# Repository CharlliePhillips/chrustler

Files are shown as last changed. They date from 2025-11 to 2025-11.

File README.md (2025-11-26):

# The Chrustler
  Chrustler is a combination of the words 'chord' (what the instrument plays) 'Rust' (the language the software is written in) and 'sampler' (the family of instruments it belongs to). This instrument takes in samples recorded using the device or loaded from a USB drive and detects their frequency. Then the user can play that sample as chords in one of the western music scales. The device runs Raspbian Linux and the Rust program in this repo is started automatically by placing the [autostart folder](https://github.com/CharlliePhillips/chrustler/tree/main/autostart) in `~/.config`. This is my final project for CS3651 (Prototyping Intelligent Devices) at Georgia Tech.  [A video demonstration is available on Youtube.](https://youtu.be/KlqjkN_t0CQ)

## Hardware
  1. Brains: Raspbery Pi Zero 2 W  
    - Runs the software itself.
  2. I2S audio card: IQuadIO Codec Zero  
    - Used for internal mic and speaker, AUX in and out headers.  
    - Also has a 5 band EQ used for the high and low pass filters.
  3. Display: SSD1309 I2C (128x64 2.5in OLED)  
    - Displays current playback information.
  4. Time of Flight sensor: ST Micro VL53L1X  
    - Has 2 regions of interest where the right side controls the level of the high frequencies (low pass filter), and the left side controls the level of the low frequencies (high pass filter)
  5. MCP23017 GPIO extender  
    - Provides additional GPIO for keypad input.
  5. PD Trigger Board  
    - Takes USB-C PD and turns it into 5V to power everything.
  6. USB-C “flush” mount extension  
    - This is intended for installation in a car to add a USB-C port, but provides a way to panel mount the power input (and USB-C is better than micro-B on the pi).
  7. 2x 3.5mm TRS female jacks  
    - Connected to the AUX in and out headers on the Codec Zero for external audio IO.
  8. Micro USB OTG cable  
    - Used to expose a full size USB port for portable loading and storing of sample files.
  9. 1W 8ohm 3.6cm speaker  
    - Connected to the Codec Zero as the internal speaker.
  10. Proto-board  
    - Used for a 5V and ground buses as well as I2C data and clock buses.
  11. Custom PCB for 4x4 Cherry-style mechanical key switches  
    - Designed in KiCAD and manufactured at the GT Hive to hold 16 cherry-style switches and the MCP23017. The KiCAD project and board drawings are in [/keypad_pcb/](https://github.com/CharlliePhillips/chrustler/tree/main/keypad_pcb)  
  12. 16x Otemu Lemon switches  
    - Spare linear Cherry-style switches I had that felt nice for the primary input method.  
  13. 2x Addicore AD267 Rotary Encoders (from class kit)  
    - Included in parts kit for class and used for volume adjustment, IO change, key change, and sample selection.  
  14. 1-2 GPIO duplication module  
    - Gives one set of 40 GPIO pins to connect to the Codec Zero, and another for the other GPIO devices, I2C, and power.  
  15. 8x m2.5 screws & heat set inserts
  16. 12x m3 screws & heat set inserts
  17. 3D printed Chassis  
    - Housing with standoffs to add heat-set inserts, and mount everything nicely. Designed in OpenSCAD.
  18. 3D printed faceplate with acrylic window  
    - Covers the main chassis and has inset text to identify IO ports, Encoder functions, and internal microphone location. Designed in OpenSCAD.  
    - The file for the chassis and faceplate is at [scad/chrustler chassis.scad](https://github.com/CharlliePhillips/chrustler/tree/main/scad/crustler%20chassis.scad).  
  19. 2x 3D printed standoffs  
    - used to support the Codec Zero on top of the Pi accounting for the height added by the GPIO duplicator. Designed in OpenSCAD, file is at [scad/soundcard standoff.scad](https://github.com/CharlliePhillips/chrustler/tree/main/scad/soundcard%20standoff.scad)  
  20. 16x 3D printed keycaps  
    - Custom 3D printed keycaps with the appropriate legends built from the [keycap playground OpenSCAD repo](https://github.com/riskable/keycap_playground).  
    - My modified version of the keycap plaground file is at [/scad/keycap_playground/keycap_playground.scad](https://github.com/CharlliePhillips/chrustler/tree/main/scad/keycap_playground/keycap_playground.scad). This was used to make a base stl file, and then imported to [/scad/legend_caps.scad](https://github.com/CharlliePhillips/chrustler/tree/main/scad/legend_caps.scad) to add the legends.
  21. 2x encoder caps  
    - Spares I had from an SP404-OG after replacing them on that device.

## Libraries
  I wanted to write the software in Rust from the start and it provides a nice way to handle interrupts/multithreading, errors, and has pretty good library support on Raspberry Pi devices. I used Rust's standard library, and a couple of other common ones such as `serde` for storing the time of flight sensor's calibration data. The notable libraries used in the program are:
  1. [pitch-detection](https://docs.rs/pitch-detection/latest/pitch_detection/)  
    - Provides a function for detecting the audio frequency on an array of individual sample points from an audio file.
  1. [awedio](https://docs.rs/awedio/latest/awedio/index.html)  
    - This library handles the playback of samples and provides functions to adjust the speed of the sample (very important for pitch correction) as well as a controller to stop/gate the playing samples.  
    - During development I kept running into an integer overflow issue when playing long samples. To fix this I changed a bunch of the related variables from unsigned 32 bit to unsigned 64 bit numbers.  
    - [My fork](https://github.com/CharlliePhillips/awedio64)
  2. [vl53l1x-rs](https://docs.rs/vl53l1x/latest/vl53l1x/)  
    - This library provides functions for the time of flight sensor.  
    - This nor any other 3rd party library I could find supported all five calibration functions, and so I added wrappers to the ST Micro API for them.  
    - Additionally the `usleep()` function in the ST Micro library this crate wraps wasn't compiling on the Pi, so I changed it to `nanosleep()`.  
    - [My fork](https://github.com/CharlliePhillips/vl53l1x-rs)
  3. [rppal](https://docs.rs/rppal/latest/rppal/)  
    - Provides functions to access the GPIO and I2C hardware on the Pi.
  4. [mcp23017](https://docs.rs/mcp23017/latest/mcp23017/)  
    - Provides functions to interface with GPIO on the MCP23017.
  5. [ssd1306](https://docs.rs/ssd1306/latest/ssd1306/)  
    - Provides structures and functions to interface with an SSD1306 display.  
    - The SSD1306 display is identical to the SSD1309 display used for this project (aside from the physical size, and default address), and by changing the I2C address provided during initialization is cross-compatible.
  6. [embedded-graphics](https://docs.rs/embedded-graphics/latest/embedded_graphics/)  
    - Provides structures and functions for creating the text shown on the display.  

  - The libraries' documentation is linked where their git repos can also be found.

  - I also used the [BOSL2](https://github.com/BelfrySCAD/BOSL2) OpenSCAD library for making cubes with rounded corners.

## Learned Skills
  1. Time of Flight Sensor(s)  
    - Before taking on this project I was totally unaware that this type of distance sensor existed. I had originally intended to use an ultrasonic sensor, or a more traditional IR sensor.  
    - I picked the model of ToF sensor I did because of it's existing Rust library support, and the user programmable Regions of interest. Those regions of interest will still pick up on objects outside the region of interest if they cover enough of the sensor's field of view but work reasonably well with two hands at different distances.  
    - It is pretty easy to interface with the sensor over I2C but they do not come calibrated from the factory and must go through a 3-step calibration process in order to get accurate readings that properly distinguish between the regions of interest.  
      1. SPAD - This is calibrated at the factory but without a cover glass that I used on my prototype. It selects the best of the sub-sensors on the device to use.  
      2. Offset - The device being soldered down and added cover class can introduce an offset in distance readings, this measures and corrects for that.  
      3. Cross-talk - The cover glass can cause some of the light emitted to bounce back into the sensor prematurely. This step compensates for that.  
  2. Heat set inserts (talk about borked one)  
    - I was familiar with this process before but had never done it myself. Getting the holes for the inserts correct took some trial and error, and when it came to insert some for testing I found that making a hole bigger with a soldering iron while the insert is half-inserted is a quick way to get plastic stuck in the insert and make it unusable.
  3. Multi-color 3D printing  
    - I had only done single-colored prints before and OpenSCAD has support for color, but it will not export those colors with STL files. In order to add color I created a small indent in the parts that the Bambu slicer would not recognize as a seperate layer, and then used the color painting/fill tool with edge detection to color the text.  
    - I also found that printing the "base" color before the text caused it to come out messy and distorted. When the text is printed before the rest of each layer though, it comes out crisp and very nice looking.  
    - Example of printing the base color before the text:  
    Example photo  
    - Printing the parts face down (with the text on the bottom layers) also gives the final product a clean, textured finish. See the photos at the end for the final product.
  4. Iterating on CAD designs  
    - The core part of the chassis has a lot of pretty precise measurements to hold everything in place. Instead of re-printing the entire base (10+ hours) each time I had to make an adjustment, I printed skeletons and small sections of the part to make sure everything fit.  
    - Using pins printed where the screws would go later helped hold things in place when test fitting the hardware.  
    - This was also useful for getting the sizing of the keycaps correct given that I'm using a non-standard plate.  
    - The following photos go left to right, top to bottom for first iterations to most recent:  
      - Main Chassis Skeleton:  
      4 iterations of a skeleton for the main chassis
      
      - IO Panel:  
      2 iterations of the rear IO panel with 2xTRS jacks and one USB-C jack  

      - USB panel and restraint:  
      3 iterations of the USB panel and internal restraint posts  

      - Keycaps:  
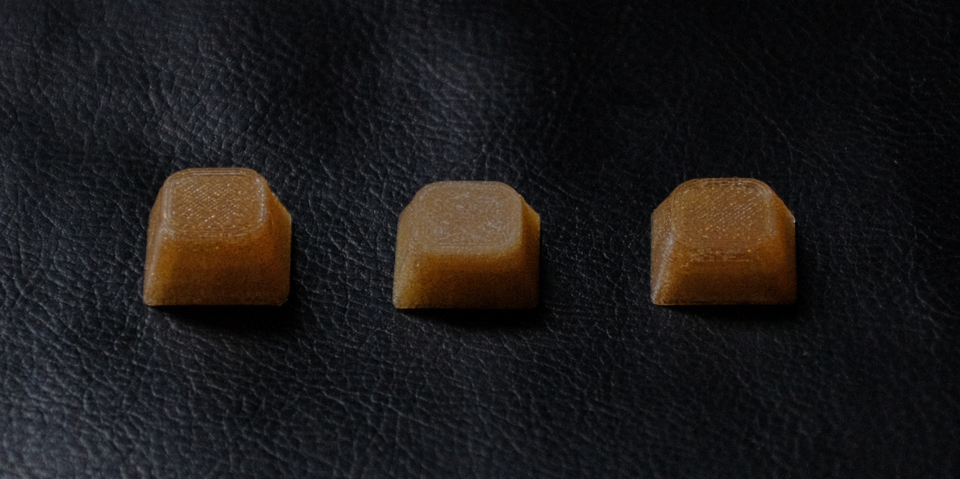
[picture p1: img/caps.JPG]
3 test keycaps of slightly different vertical sizes
        

  5. Linux audio  
    - I've used Linux for quite some time to do multimedia work (always requires some fidling), but I haven't had to get in the weeds quite like this before.  
    - The volume, filter and adjustments along with the IO toggle both use `amixer` commands issued by the Rust program to change the relevant settings. This was easy to test using the `alsamixer` TUI and then translate into commands using the indices given by `amixer -c -1 controls`.  
    - I used `arecord` commands issued by the Rust program to do the audio recording as the simplest Rust interfaces for this were overcomplicated for my use case. When testing recording and playback in the final program I ran into a weird issue with lots of noise in the recordings from the program that didn't exist using the commands by themselves. After some troubleshooting I discovered that the audio device was opened in 32 bit PCM mode by the `awedio` library but I was recording in 16 bit mode as that is the actual format used by the library. Switching the recordings to 32 bit mode fixed this issue.
  6. PCB Fabrication  
    - To have a "macro" pad with Cherry-style switches that fit in the small size I wanted for the enclosure I had to design my own.  
    - Picking up KiCAD to recreate the simple circuit from the membrane pad given in our class kits was fairly easy, and a lot of resources exist online from the custom keyboards community to quickly get a model running. There was also a fellow student familiar with the process who was able to give me some design tips to make sure that my first run of the board would work, and be my last.  
    - The Hive makerspace at school had excellent documentation on using their PCB fabrication equipment (LPKF ProtoMat S103, and ProtoLaser U4). From there it was fairly easy to get everything going, and once finished then I was able to solder the switches and MCP23017 using my own equipment.  
    - The underside of the keypad PCB (the top side is just plain copper):  
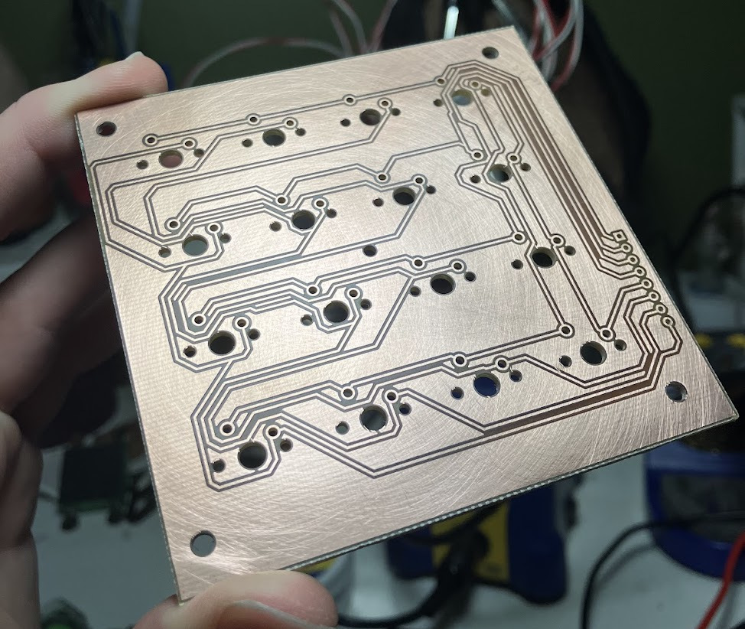
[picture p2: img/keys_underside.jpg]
Copper PCB
    

  7. Acrylic Crazing and I2C Speed/Capacitance Relationship  
    - These two weren't part of skill demos for the class but my instructor Scott taught me about these when I was curious about some of these finer details.  
    - Securing acrylic with the right adhesive is important, as many adhesives will cause stress on top of that introduced by laser cutting. This additional stress can cause micro-cracks called "crazing" and is caused by adhesives with solvents like alcohol. To demo this he sprayed some dry erase fluid on an some laser cut acrylic scrap, and cracks started to form in less than a minute.  
    - I had some extra JB weld and thought that might work well so I used it on another piece of acrylic scrap and attached it to the first chassis skeleton (but it broke during stress testing):  
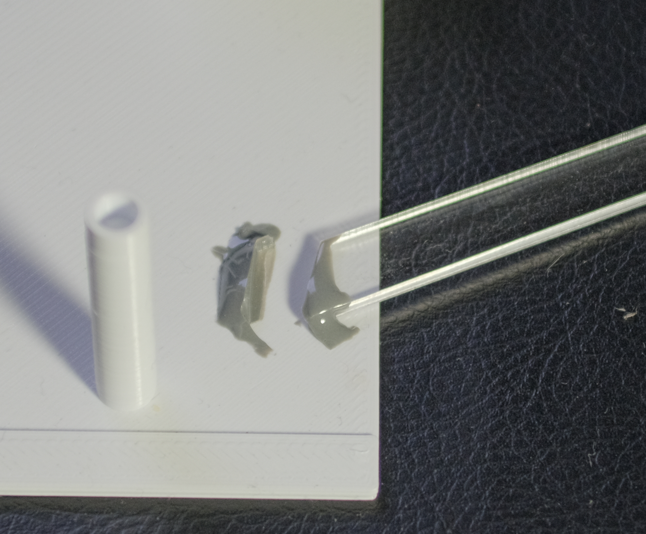
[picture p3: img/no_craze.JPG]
Close up of acrylic and PLA with JB weld globs
      
    - I was worried about cramming too much near the I2C bus circuitry and causing interference. I2C operates at a constant clock but the data experiences some curve in the rise time of the signals. Scott explained how this curve is dictated by the capacitance of the wires which ensured me that I didn't have to be too careful about where to place these signal wires inside of the enclosure.  

## Iteration Process
### Initial Testing
  1. Proof of Concept Program.  
    - My first work on this project was a simple program that recorded a sample, then corrected the pitch it and played back as a C-Major triad.  
    - Once I had acquired some of the hardware for the prototype I added the time of flight sensor readings to adjust a filter on this chord as it looped indefinitely.  
    - [Repo for this test](https://github.com/CharlliePhillips/crustler_poc)
  2. GPIO Test Program   
    - I also created a separate test program to hook up the remainder of the input hardware to to figure out a good setup for reading everything but the TOF sensor.  
    - [Repo for this test](https://github.com/CharlliePhillips/chrustler_btn_test)
  3. Testing Breadboard  
    - For these test programs and much of the development of the main program I had all of the hardware connected to a breadboard. This made it easy to disconnect things to take measurements for the chassis while still working on the main program, and experiment minimizing the wires needed to connect everything.  
    - Having everything on the breadboard made it easy to hook up parts to the chassis skeleton(s):
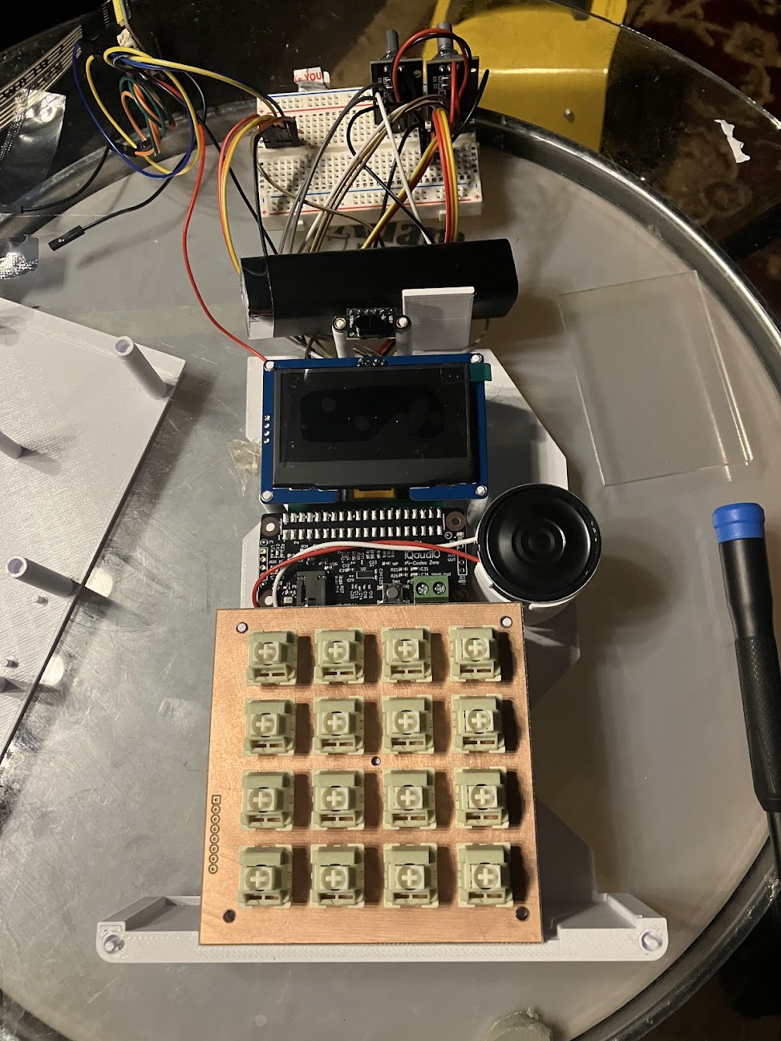
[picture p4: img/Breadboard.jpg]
breadboarded electroncs with some placed on 3D printed skeleton
      

### Ideas That Didn't Work Out
  1. Battery Power  
    - I had initially planned to add battery power to the device for portability. As I worked on the physical design and test fit the rest of the hardware I realized that there would not be a whole lot of room for the battery, and given the time constraint on the project decided that it could do without and USB-C PD would suffice.  
  2. Filter frequency sweeping  
    - I originally wanted to have the TOF sensor control both the frequency and intensity of the filters with a multi-zone sensor where the frequency would be set by the zone(s) and intensity controlled by the distance, but with poor documentation and 3rd party library support this was out of reach.  
    - When moving to a ROI sensor instead of multi-region one I had instead wanted a fixed intensity where the distance controlled the frequency, but I then found that the audio card I had decided on has a built in 5 band EQ, but it is not parametric.  
    - I finally landed on the distance controlling the intensity of the lower two and upper two frequency bands provided by the built in EQ. The intensity of the "inner" band of each side is halved from the intensity set to the highest and lowest end of the EQ, and this works fairly well as a high, low, or band pass filter.

### Hardware That Had To Be Changed
  1. Keypad
    - As alluded to before I originally was using a 4x4 membrane keypad as the primary input for the device. This really sucked,  it was hard to tell when I was pressing the button or not, and it was very small making it a little hard to play multiple chords in succession.
    - This shows how small the original pad was compared to the one I made:  
    final product next to small membrane keypad
    - Creating my own keypad fixed these problems, and also let me change the legends on the keys for a more intuitive arrangement of the inputs.  
  2. SD Card – OTG adapter
    - My original idea for loading external sound files was to use an SD card like on devices like the SP404 MKII and modern (or modernized) MPC devices. This is sort of what the format is intended for, but requires an SPI connection from the limited GPIO I had after adding the sound card.  
    - To simplify things I decided to mount a micro-B OTG adapter inside of the device that connects directly to the Raspberry Pi. This let me focus on getting the file navigation part of my code working correctly and should theoretically not be too difficult if I were to add it in the future.  

### Lessons Learned
  1. Calibrate Your ToF Sensor    
    - Before calibration the ToF sensor readings where all over the place. Adding the Rust calibration functions to the library I used and sitting through the calibration process was something I should have considered from the start and was absolutely worth it.
  2. Consider cable management  
    - Despite not needing to be too worried about I2C interference I should have spent some more time considering where to route all of the wires inside of the device. It is a bit of a rats nest, and with a little more thought, I think I could do much better.  
  3. Test Physical Design With Small Parts   
    - The 3D print iterations shown above were key to getting my physical design just right.  
    - I hadn't taken on a 3D modeling and design project of this scale before, and had never needed to do more than a couple of full prints to get something the way I wanted. I was still pretty uncertain about my measurements at each stage and printing only the parts I was concerned about saved me a lot of time and filament.  
  4. ALSA(mixer) is fun  
    - Using the ALSA programs that come with Raspbian Linux (and most desktop Linux distros) made a lot of things I was uncertain about programming much easier than anticipated.  
    - If I ever do other audio-intense programming projects I will be considering some of these same techniques to make my life easier. I know this is sorta the "Unix Philosophy" but often times built in programs don't come with quite everything I want them to, and this was not the case here.  

  #### Other Potential Improvements
  1. More thorough recording (i.e. adjustable count in, timed recording, input level)  
    - Other sampler instruments offer these sorts of things, and they could be useful here as well.
  2. Simple sample trimming  
    - This would mean you don't have to start playing your recording as soon as or before the recording starts, and would be a very nice qol feature.
  3. Analog Chord Keys  
    - Using optical or hall-effect analog mechanical keyboard switches could be a nice way to keep the same form factor while adding velocity to the input. This would require a more complex PCB though and those switches are much harder to come by.
  4. Stereo sound  
    - All of the sound on this device is mono, and the audio IO is all wired as mono. This was to reduce possibilities while programming and still sounds great (especially for a prototype), but stereo is the standard and would improve the quality of the sound produced.  

## The Final Prototype
A photo taken during assembly:
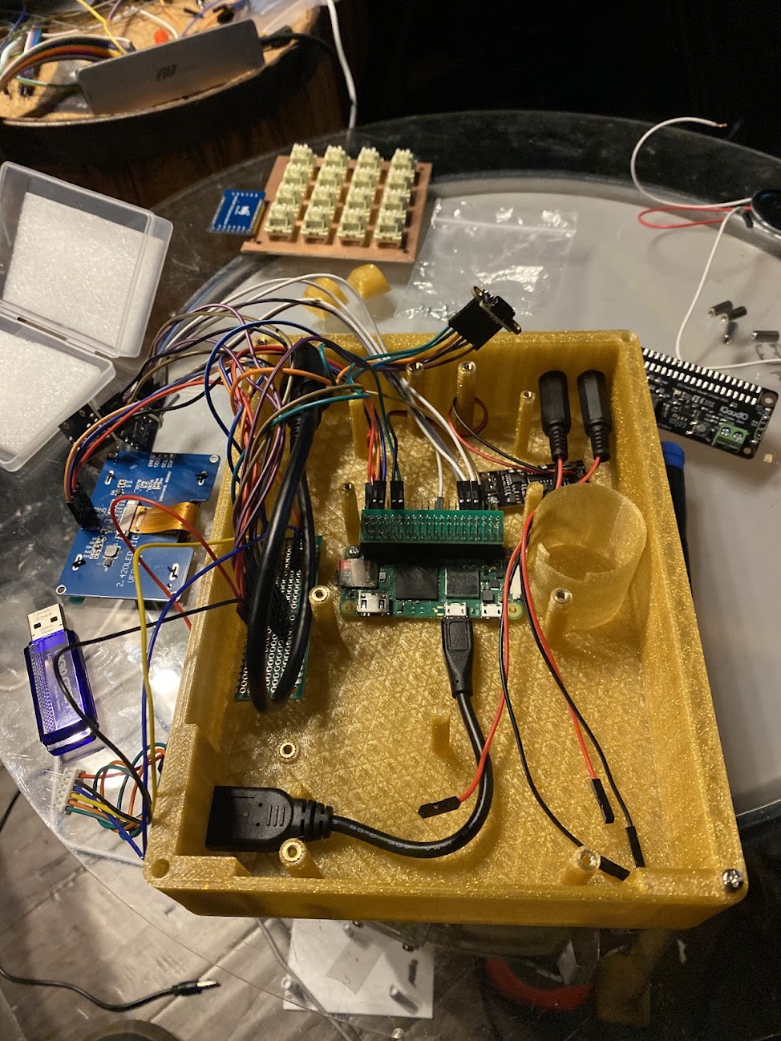
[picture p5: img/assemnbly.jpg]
assembly photo


Overview of the final prototype:
overview photo

Main IO panel on the final prototype:
IO Panel

USB Panel on the prototype:
USB Panel

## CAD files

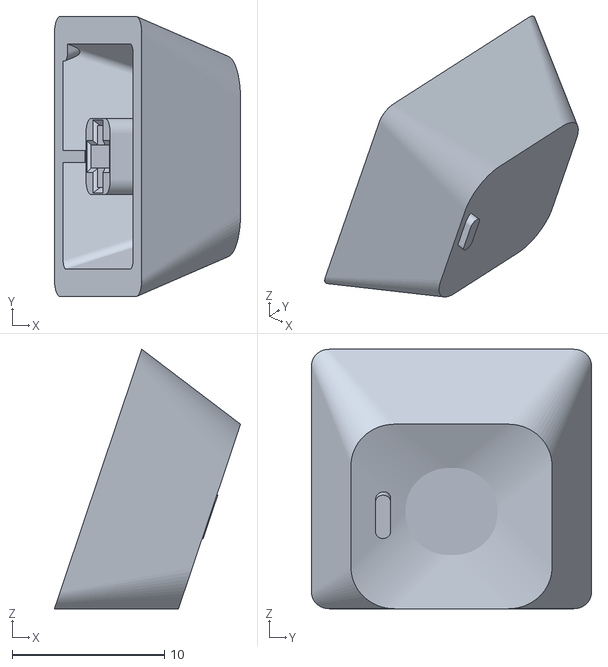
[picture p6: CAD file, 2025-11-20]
scad/keycap_playground/pregenerated/Riskable Profile 4.0 (Homing Dot).stl
12.2 x 18.4 x 17.1

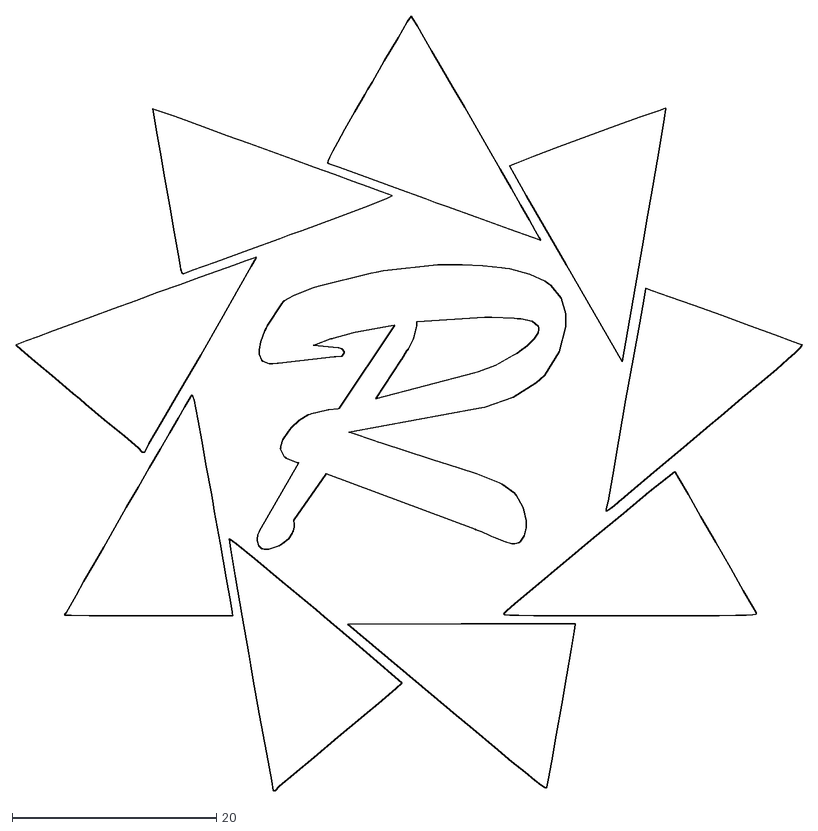
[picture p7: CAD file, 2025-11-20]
scad/keycap_playground/riskable_logo.dxf
76.9 x 75.8

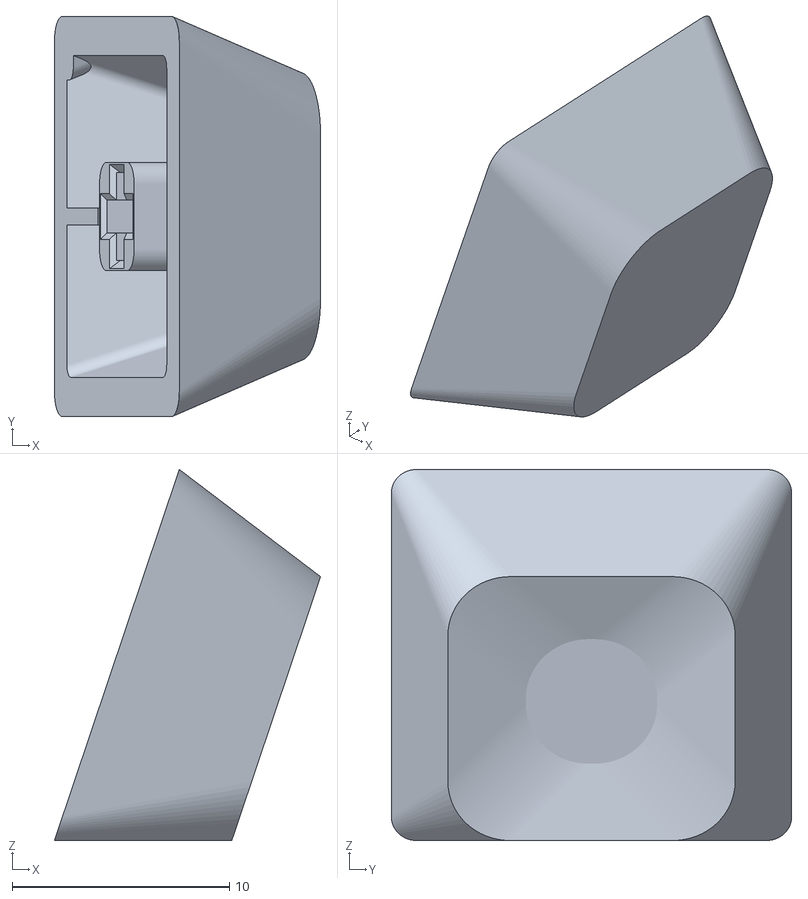
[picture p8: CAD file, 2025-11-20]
scad/keycap_playground/pregenerated/Riskable Profile 4.0.stl
12.2 x 18.4 x 17.1

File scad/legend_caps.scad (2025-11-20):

$fn=32;

difference() {
    import("chrustler_keycap_base.stl");

    translate([0,0,7])
    linear_extrude(.4)
        text("I", size=6, halign = "center", valign = "center");
}

translate([20,0,0])
difference() {
    import("chrustler_keycap_base.stl");

    translate([0,0,7])
    linear_extrude(.4)
        text("II", size=6, halign = "center", valign = "center");
}

translate([40,0,0])
difference() {
    import("chrustler_keycap_base.stl");

    translate([0,0,7])
    linear_extrude(.4)
        text("III", size=6, halign = "center", valign = "center");
}

translate([60,0,0])
difference() {
    import("chrustler_keycap_base.stl");

    translate([0,0,7])
    linear_extrude(.4)
        text("mod", size=5, halign = "center", valign = "center");
}

translate([0,-20,0])
difference() {
    import("chrustler_keycap_base.stl");

    translate([0,0,7])
    linear_extrude(.4)
        text("IV", size=6, halign = "center", valign = "center");
}

translate([20,-20,0])
difference() {
    import("chrustler_keycap_base.stl");

    translate([0,0,7])
    linear_extrude(.4)
        text("V", size=6, halign = "center", valign = "center");
}

translate([40,-20,0])
difference() {
    import("chrustler_keycap_base.stl");

    translate([0,0,7])
    linear_extrude(.4)
        text("VI", size=6, halign = "center", valign = "center");
}

translate([60,-20,0])
difference() {
    import("chrustler_keycap_base.stl");

    translate([0,0,7])
    linear_extrude(.4)
        text("gat", size=6, halign = "center", valign = "center");
}

translate([0,-40,0])
difference() {
    import("chrustler_keycap_base.stl");

    translate([0,0,7])
    linear_extrude(.4)
        text("VII", size=6, halign = "center", valign = "center");
}

translate([20,-40,0])
difference() {
    import("chrustler_keycap_base.stl");

    translate([0,0,7])
    linear_extrude(.4)
        text("<oc", size=5, halign = "center", valign = "center");
}

translate([40,-40,0])
difference() {
    import("chrustler_keycap_base.stl");

    translate([0,0,7])
    linear_extrude(.4)
        text("oc>", size=5, halign = "center", valign = "center");
}

translate([60,-40,0])
difference() {
    import("chrustler_keycap_base.stl");

    translate([0,0,7])
    linear_extrude(.4)
        text("tof", size=6, halign = "center", valign = "center");
}

translate([0,-60,0])
difference() {
    import("chrustler_keycap_base.stl");

    translate([0,0,7.175])
    //linear_extrude(.4)
    //    text("O", size=6, halign = "center", valign = "center");
    cylinder(h=.4,r=3,center=true);
}

translate([20,-60,0])
difference() {
    import("chrustler_keycap_base.stl");

    translate([0,0,7])
    linear_extrude(.4)
        text("f", size=6, halign = "center", valign = "center");
}

translate([40,-60,0])
difference() {
    import("chrustler_keycap_base.stl");

    translate([0,0,7])
    linear_extrude(.4)
        text("hld", size=6, halign = "center", valign = "center");
}

translate([60,-60,0])
difference() {
    import("chrustler_keycap_base.stl");

    translate([0,0,7])
    linear_extrude(.4)
        text("typ", size=6, halign = "center", valign = "center");
}

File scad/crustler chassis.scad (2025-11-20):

$fn = 64;
include<BOSL2/std.scad>

//CHASSIS
union() {
difference() {
    translate([0,0,22.5])
    cuboid([200,150,45], rounding = 5, except = [TOP,BOT] );
    
    translate([0,0,28.5])
        cube([185, 135, 45], center=true);
    
    translate([93.5,-1.5,28.5])
        cube([7, 100, 39], center=true);
    
    translate([18,-69,30])
        cube([80,5,45], center=true);
    
    {//bus support heatset
        translate([-12.5,-48.5,4.5])
        cylinder(h=6, r=2.4,center=true);
        
        translate([52.5,-48.5,4.5])
        cylinder(h=6, r=2.4,center=true);
    }
    
    {//PD support heatset
        translate([-57.25,20,4.5])
        cylinder(h=6.1, r=1.6,center=true);
        
        translate([-42.75,20,4.5])
        cylinder(h=6.1, r=1.6,center=true);
    }
    
    {//PI support heatset
        translate([-21,25.5,4.5])
            cylinder(h=6.1, r=1.6,center=true);
        
        translate([-21,-32.5,4.5])
            cylinder(h=6.1, r=1.6,center=true);
    }
    
    { // heatset lid
        translate([95.5,70.5,42])
            cylinder(h=6.5, r = 2.4, center=true);
        translate([-95.5,70.5,42])
            cylinder(h=6.5, r = 2.4, center=true);
        translate([95.5,-70.5,42])
            cylinder(h=6.5, r = 2.4, center=true);
        translate([-95.5,-70.5,42])
            cylinder(h=6.5, r = 2.4, center=true);
    }
    
    translate([-96.25,-55,25]) { // PWR jack
        difference() {
            rotate([0,90,0])
                cylinder(h=9, r = 8, center=true);
            
            translate([0,8.125,0])
                cube([9,1,5],  center = true);
        }
    }
    
    { //HP jack
        translate([-96.25,60,25])
        rotate([0,90,0])
            cylinder(h=9, r = 4.75, center=true);
        
        //translate([-94.8,55,25])
        translate([-95.05,60,25])
        rotate([0,90,0])
            cylinder(h=7.5, r = 5.875, center=true);
    }
    
        { //in jack
        translate([-96.25,45,25])
        rotate([0,90,0])
            cylinder(h=9, r = 4.75, center=true);
        
        //translate([-94.8,55,25])
        translate([-95.05,45,25])
        rotate([0,90,0])
            cylinder(h=7.5, r = 5.875, center=true);
    }
    
    { // USB jack
        translate([75, -71.25, 11.25])
            cube([14.5, 8, 7.5], center=true);
        
        translate([75, -69, 11.75])
            cube([18.5, 7.5, 11.5], center=true);
    }
}
    
    {//USB restraint
        translate([84,-44,9.5])
            cube([4, 4, 8],center=true);
        
        translate([66,-44,9.5])
            cube([4, 4, 8],center=true);
    }
    
    difference() {
    translate([-10,48,6]) difference() { // speaker support
        cylinder(h=36.7,r=18,center=false);
        
        cylinder(h=37,r=17, center=false);
        translate([0,-18,19])
        cube([12,4,37],center = true);
    }
        translate([48, -1.75, 40])
        cube([94,94,6], center=true);
    }
    translate([51,-1.75,6]) { // keys support
        difference() {
            translate([38,40,0])
            cylinder(h=30, r=3.5,center=false);
            
            translate([38,40,24])
            cylinder(h=6.1, r=2.4,center=false);
        }
        difference() {
            translate([38,-37,0])
            cylinder(h=30, r=3.5,center=false);
            
            translate([38,-37,24])
            cylinder(h=6.1, r=2.4,center=false);
        }
        difference() {
            translate([-39,40,0])
            cylinder(h=30, r=3.5,center=false);
            
            translate([-39,40,24])
            cylinder(h=6.1, r=2.4,center=false);
        }
        difference() {
            translate([-39,-37,0])
            cylinder(h=30, r=3.5,center=false);
            
            translate([-39,-37,24])
            cylinder(h=6.1, r=2.4,center=false);
        }
        difference() {
            translate([-1,2,0])
            cylinder(h=30, r=2.75,center=false);
            
            //translate([-1,2,28])
            //cylinder(h=4.1, r=1.98,center=false);
        }
        translate([-1,2,28])
            cylinder(h=8, r = 0.8, center=true); 
    }
    
    translate([20,-48.5,0]) { // Bus board support
        translate([-32.5,0,6])
        difference() {
                cylinder(h=3, r=3.5,center=true);
                cylinder(h=6, r=2.4,center=true);
        }
        
        translate([32.5,0,6])
        difference() {
            cylinder(h=3, r=3.5,center=true);
            cylinder(h=6, r = 2.4, center=true);
        }
     }
     
        translate([-50,20,0]) { // PD board support
            translate([-7.25,0,6])
            difference() {
                cylinder(h=3, r=2.75,center=true);
                cylinder(h=6.1, r=1.6,center=true);
            }
            translate([7.25,0,6])
            difference() {
                cylinder(h=3, r=2.75,center=true);
                cylinder(h=6.1, r=1.6,center=true);
            }
            translate([0,34,6])
                cube([14,2,3], center=true);

     }
    
    translate([0,3.5,0]){ // pi support
    translate([2,22,6])  {
        cylinder(h=.5, r=2.75,center=true);
            translate([0,0,2])
            cylinder(h=4, r = 0.8, center=true);
    }
    translate([2,-36,6])  {// pi support
        cylinder(h=.5, r=2.75,center=true);
            translate([0,0,2])
            cylinder(h=4, r = 0.8, center=true);
    }
    translate([-21,22,6])  {
        difference() {
            cylinder(h=.5, r=2.75,center=true);
            //translate([0,0,2])
            //cylinder(h=4, r = 1.175, center=true);
            cylinder(h=6.1, r=1.6,center=true);
        }
    }
    translate([-21,-36,6])  {
        difference() {
            cylinder(h=.5, r=2.75,center=true);
            //translate([0,0,2])
            //cylinder(h=4, r = 1.175, center=true
            cylinder(h=6.1, r=1.6,center=true);
        }
    }

    }
    translate([-50, 0,6]) { // display support
        difference() {
            translate([21.5,32.5,0])
            cylinder(h=33, r=2.75,center=false);
            
            //translate([21.5,32.5,29])
            //cylinder(h=4.1, r=1.98,center=false);
        }
        translate([21.5,32.5,30.5])
            cylinder(h=8, r = 1.175, center=true); 
        
        difference() {
            translate([-21.5,32.5,0])
            cylinder(h=33, r=2.75,center=false);
            
            translate([-21.5,32.5,27])
            cylinder(h=6.1, r=1.6,center=false);
        }
        
        difference() {
            translate([21.5,-32.5,0])
            cylinder(h=33, r=2.75,center=false);
            
            translate([21.5,-32.5,27])
            cylinder(h=6.1, r=1.6,center=false);
        }
        
        difference() {
            translate([-21.5,-32.5,0])
            cylinder(h=33, r=2.75,center=false);
            
            //translate([-21.5,-32.5,29])
            //cylinder(h=4.1, r=1.98,center=false);
        }
        translate([-21.5,-32.5,30.5])
            cylinder(h=8, r = 1.175, center=true); 
    }
    
    
        translate([-84, 0,6]) { // tof support
        difference() {
            translate([0,10,0])
            cylinder(h=36, r=3.5,center=false);
            
            translate([0,10,30])
            cylinder(h=6.1, r=2.4,center=false);
        }
        difference() {
            translate([0,-10,0])
            cylinder(h=36, r=3.5,center=false);
            
            translate([0,-10,30])
            cylinder(h=6.1, r=2.4,center=false);
        }
    }
}
// M2.5 holes
// cylinder(h=4, radius = 1.98, center=true);

//M3 holes
// cylinder(h=4, radius = 2.4, center=true);

translate([0,0,146.5]) { // LID 
    //translate([0,0,23.25])
    
difference() {
    translate([0,0,-0.5])
    cuboid([200,150,2], rounding = 5, except = [TOP,BOT] );
    
    translate([2,-26.5,0])
    cylinder(h=4, r=1, center=true);
    
    { // TOF cavity
        translate([-82.5,0,0])
        cuboid([5.75,10.5,4], rounding = 2.875, except = [TOP,BOT]);
    }
    
    { // display cavity
        translate([-50,0,0])
            cube([48,70.2,4], center=true);
        translate([-50.5,-.5,-1.025])
            cube([52,74.2,1], center=true);
    }
    
    translate([0,0,-0.25]) { // pot text inset
        translate([-25,-54,.6])
        rotate([0,0,90])
        linear_extrude(.45,center=true)
        text("VOL/IO", size = 6, halign = "center", valign= "center");
        
        translate([25,-57,.6])
        rotate([0,0,90])
        linear_extrude(.45,center=true)
        text("KEY/SND", size = 6, halign = "center", valign= "center");
        
        translate([2,-16,.6])
        rotate([0,0,90])
        linear_extrude(.45,center=true)
        text("MIC", size = 6, halign = "center", valign= "center");
        
        translate([-92,0,.6])
        rotate([0,0,90])
        linear_extrude(.395,center=true)
        text("TOF", size = 6, halign = "center", valign= "center");
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

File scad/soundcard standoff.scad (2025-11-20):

$fn = 64;
include<BOSL2/std.scad>
translate([0,0,9.9])
difference() {
    cylinder(h=19.8, r = 2.75, center=true);
    
    translate([0,0,6.9])
    cylinder(h=6.1, r = 1.7, center=true);
    
    translate([0,0,-8])
    cylinder(h=4, r = 1.6, center=true);
}
//translate([5,5,4])
//union() {
//    cylinder(h=8, r = 2.75, center=true);
    
//    translate([0,0,6])
//    cylinder(h=4, r = 1.175, center=true);
//}

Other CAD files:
scad/keycap_playground/keycap_playground.scad
scad/keycap_playground/constants.scad
scad/keycap_playground/keycaps.scad
scad/keycap_playground/legends.scad
scad/keycap_playground/profiles.scad
scad/keycap_playground/snap_fit.scad
scad/keycap_playground/stems.scad
scad/keycap_playground/utils.scad

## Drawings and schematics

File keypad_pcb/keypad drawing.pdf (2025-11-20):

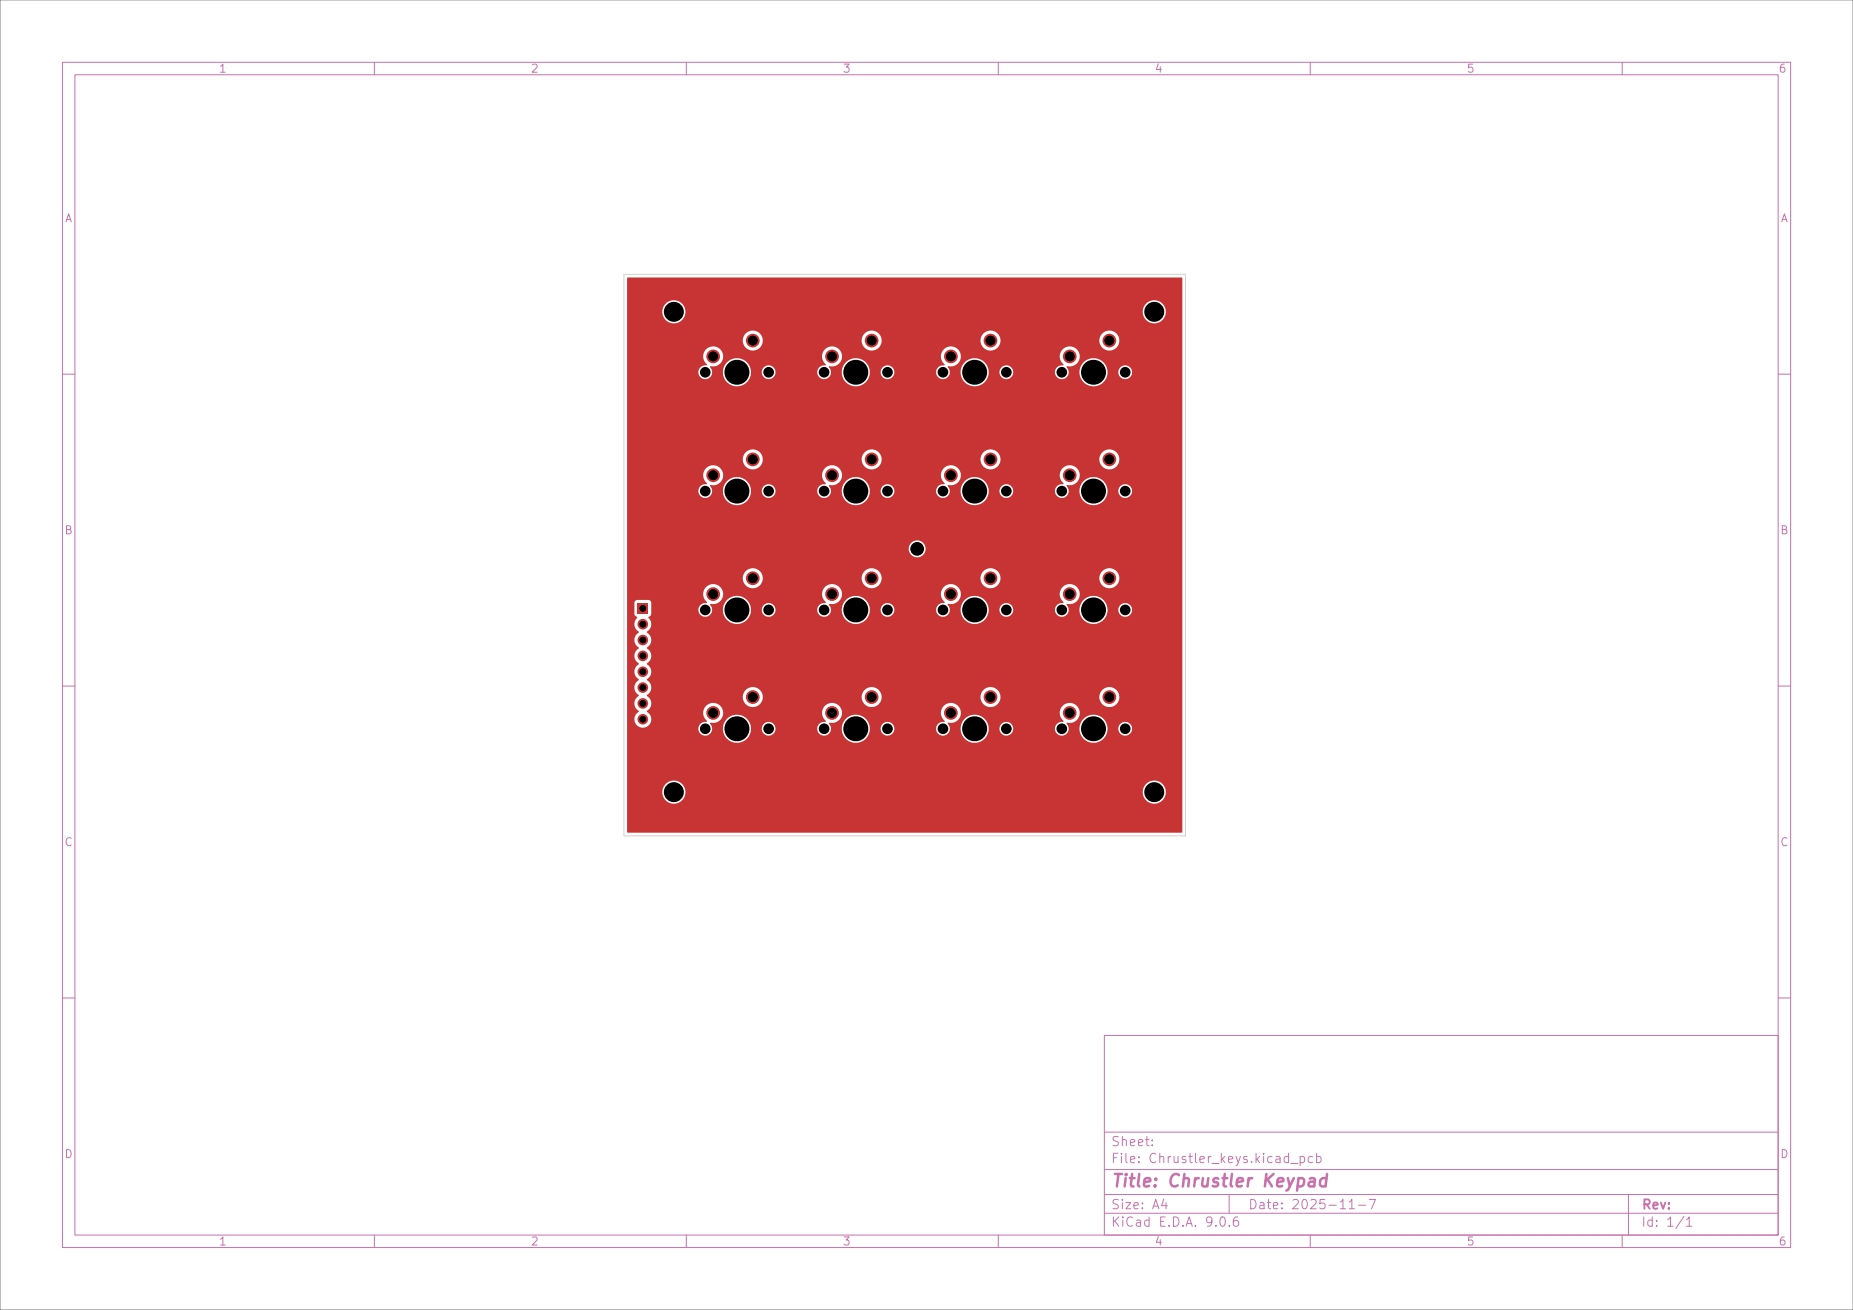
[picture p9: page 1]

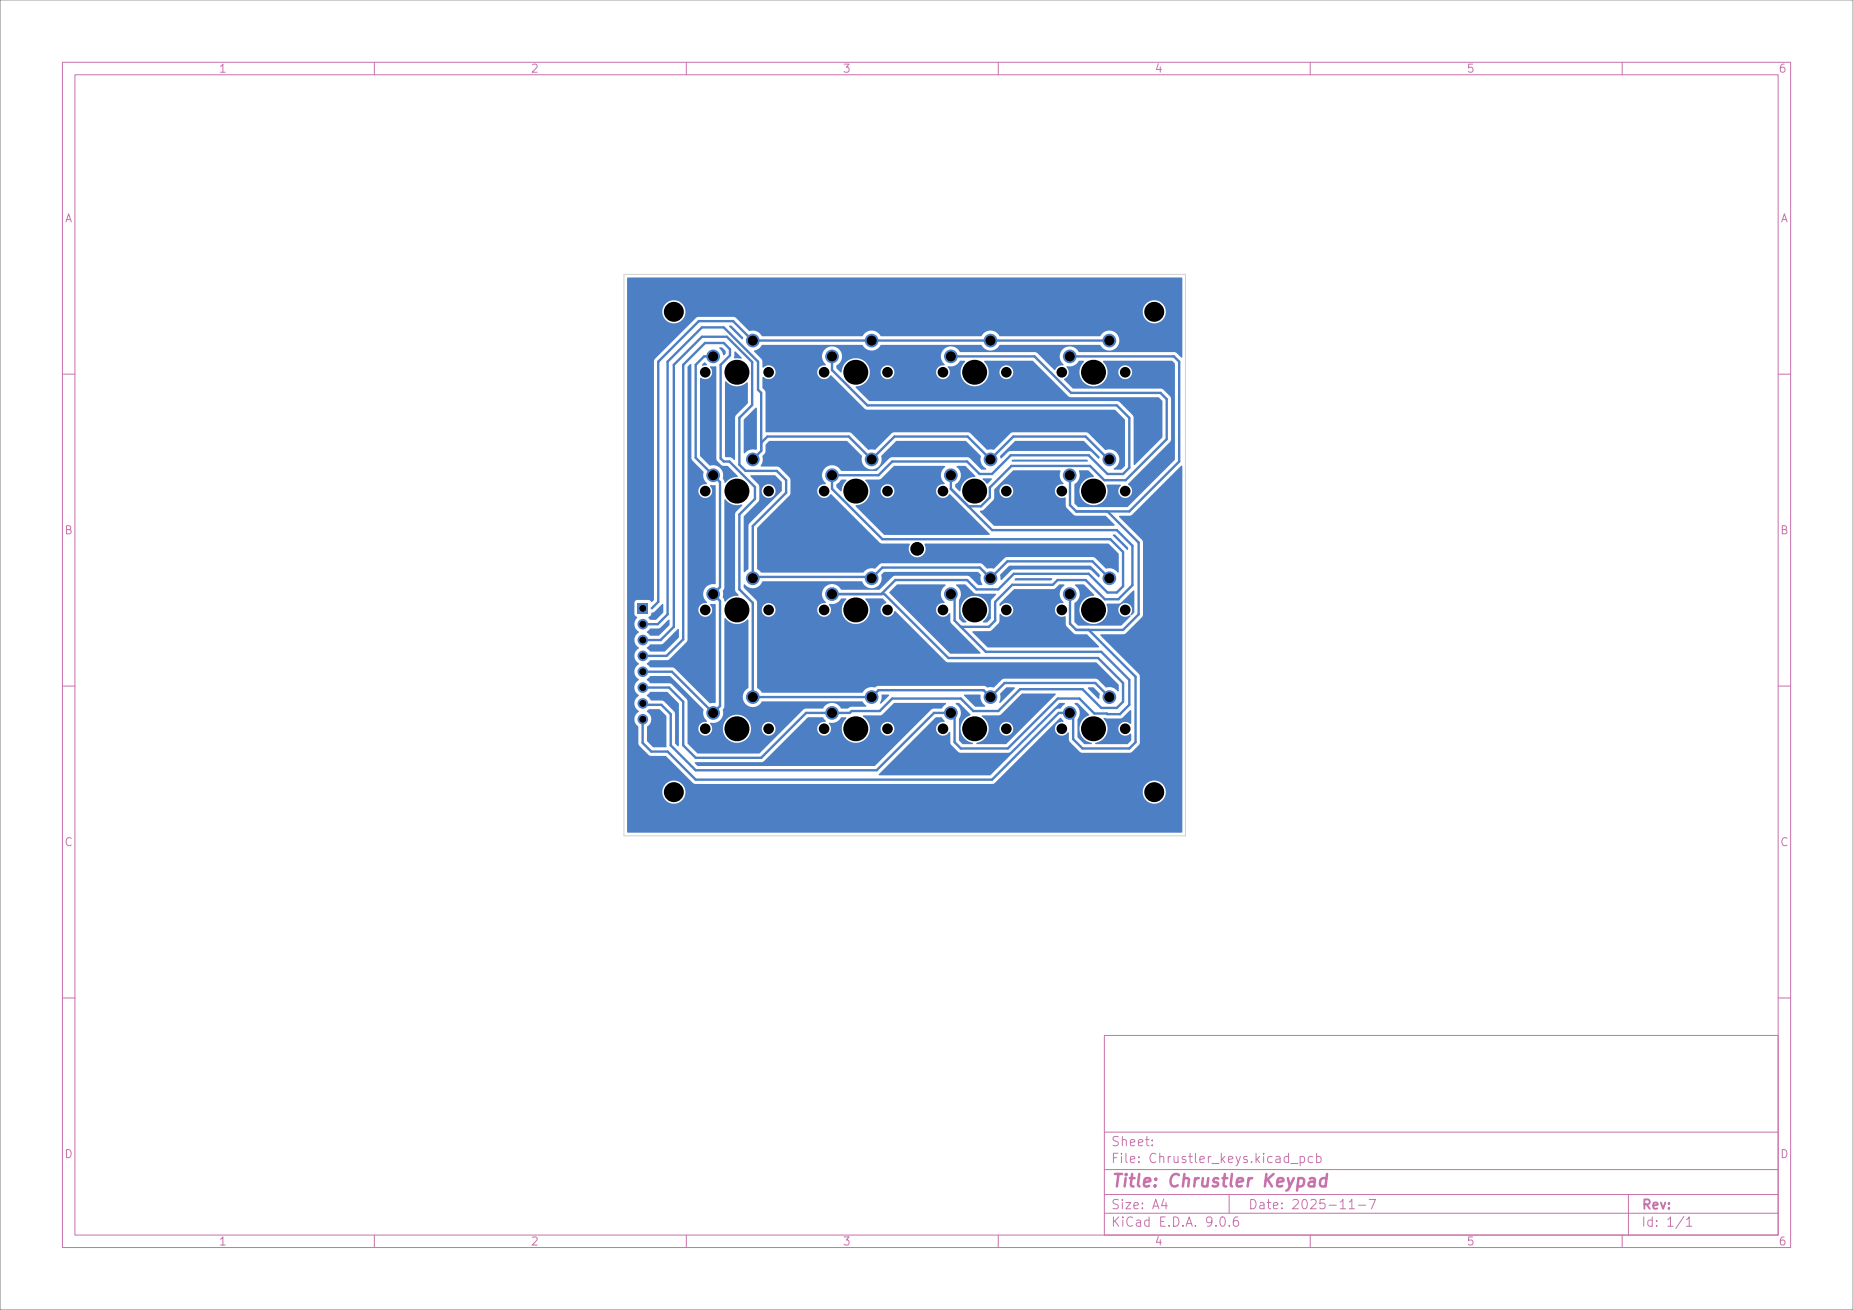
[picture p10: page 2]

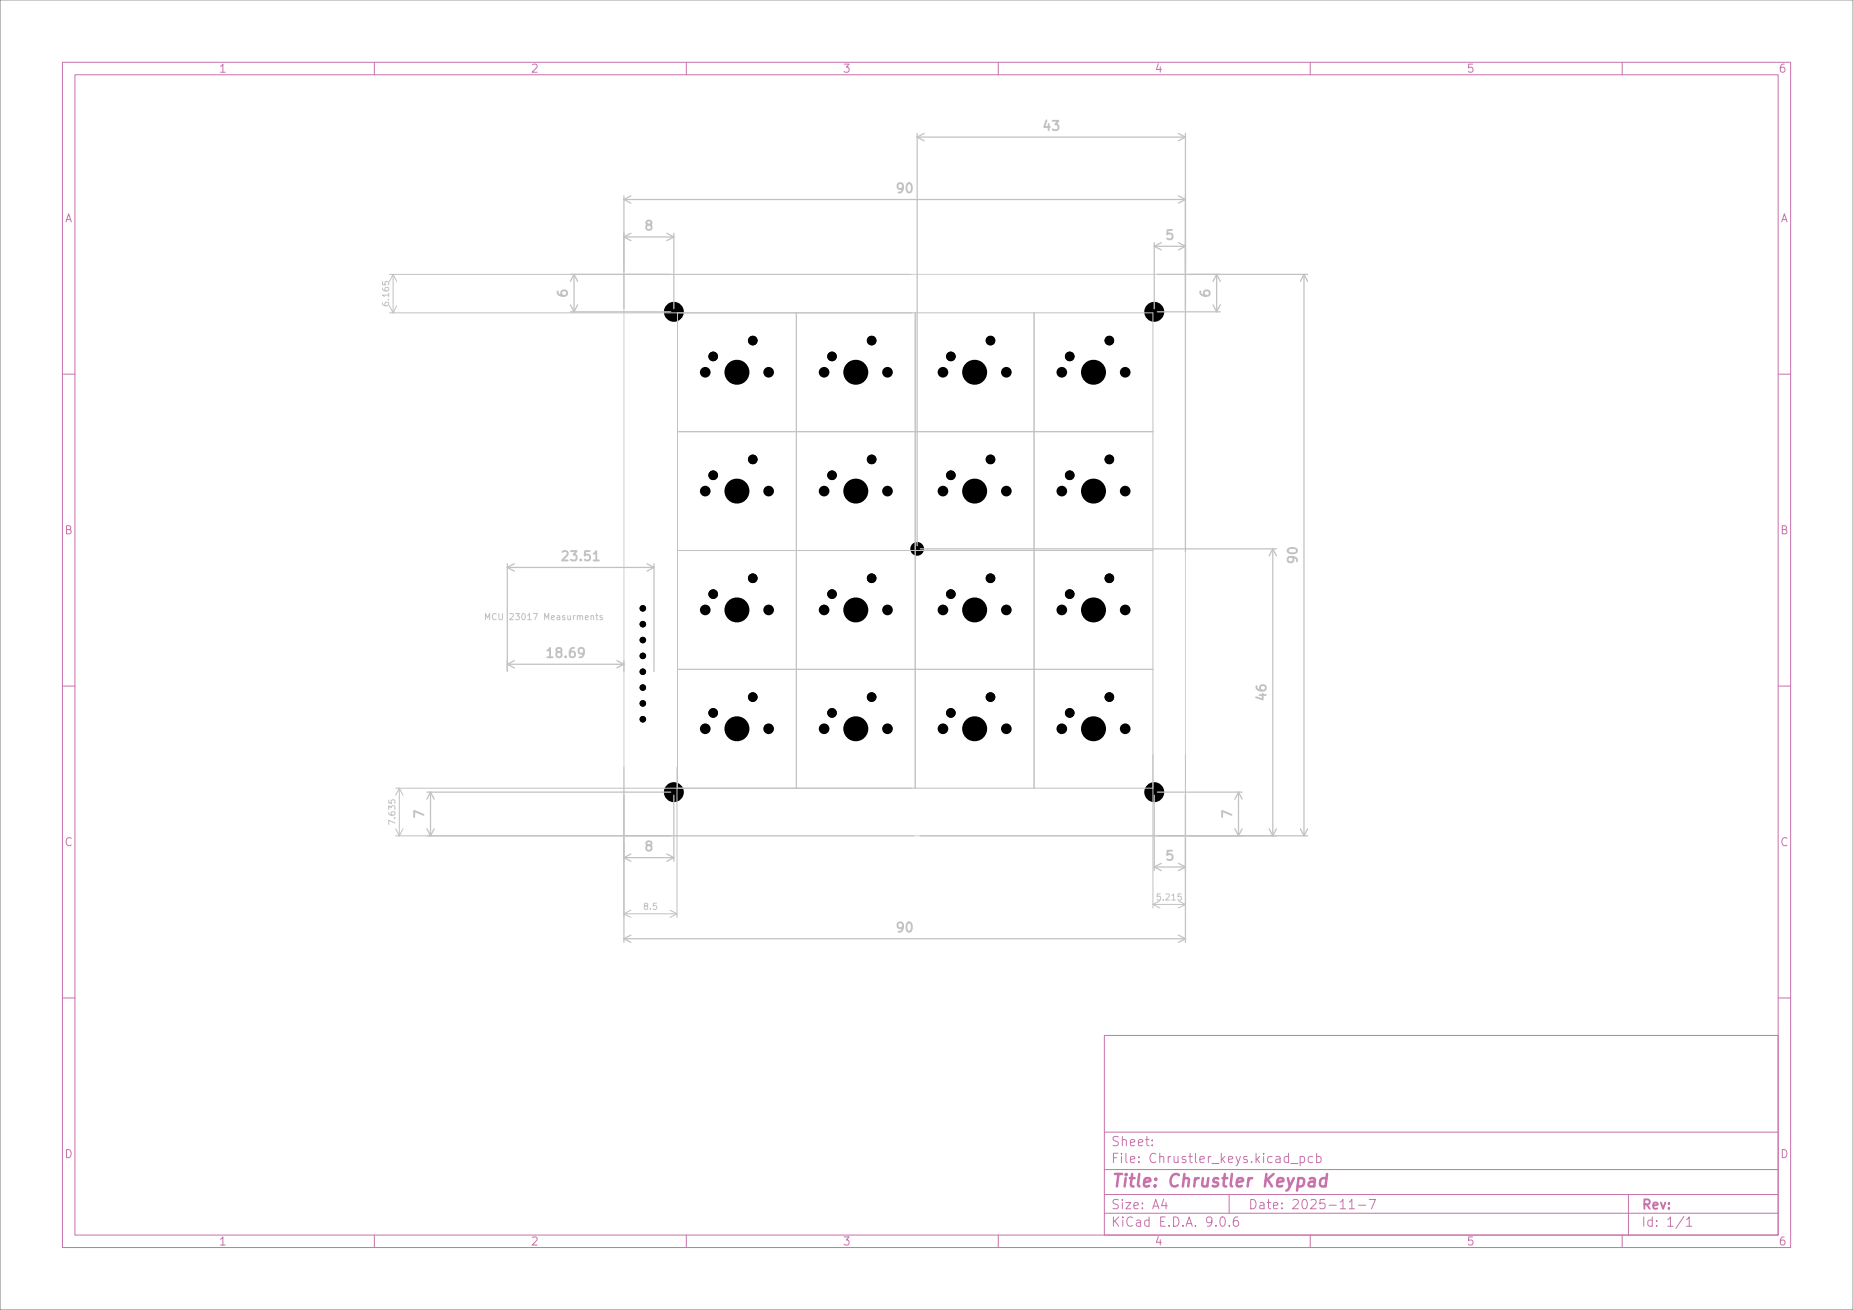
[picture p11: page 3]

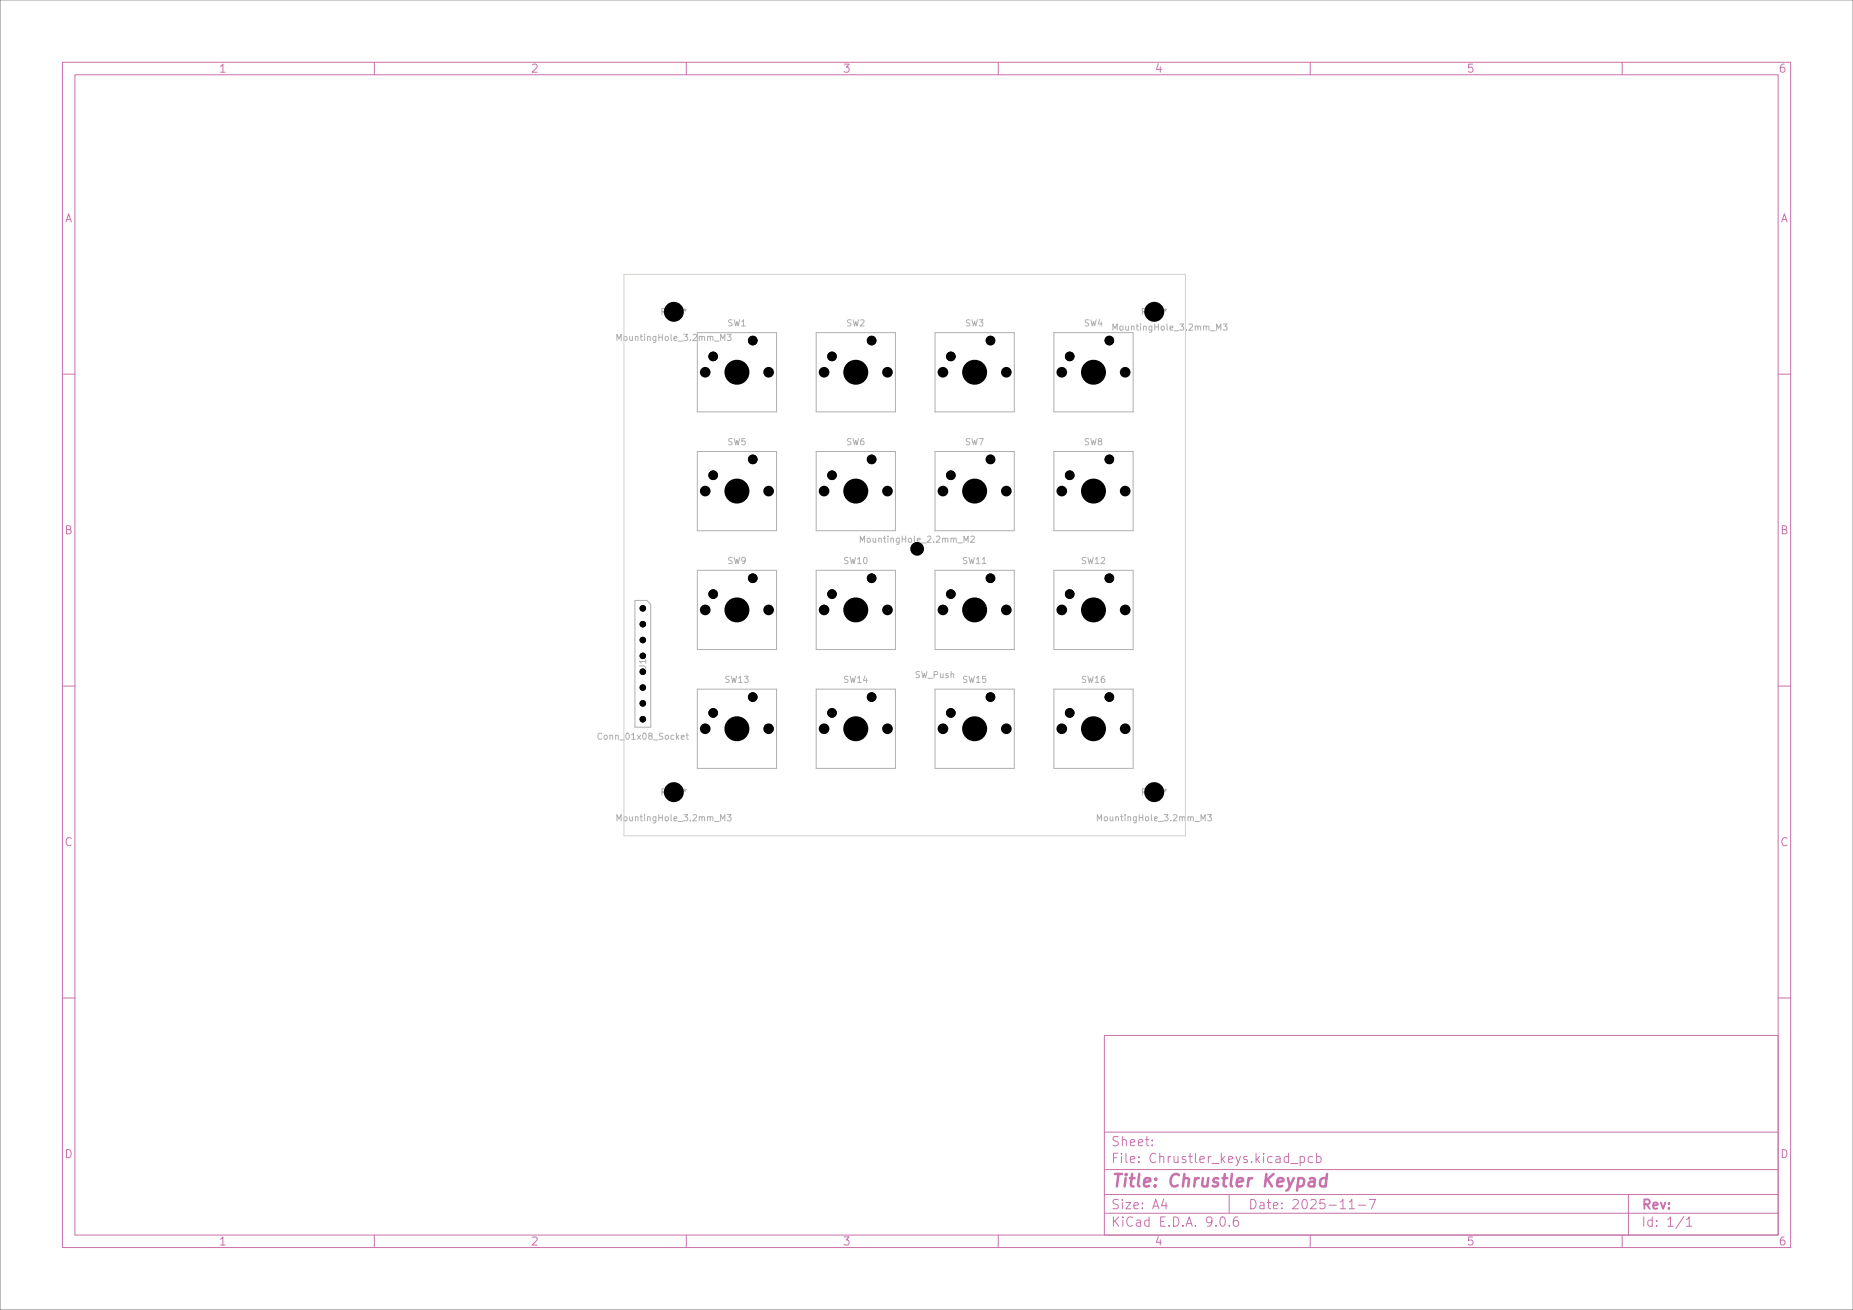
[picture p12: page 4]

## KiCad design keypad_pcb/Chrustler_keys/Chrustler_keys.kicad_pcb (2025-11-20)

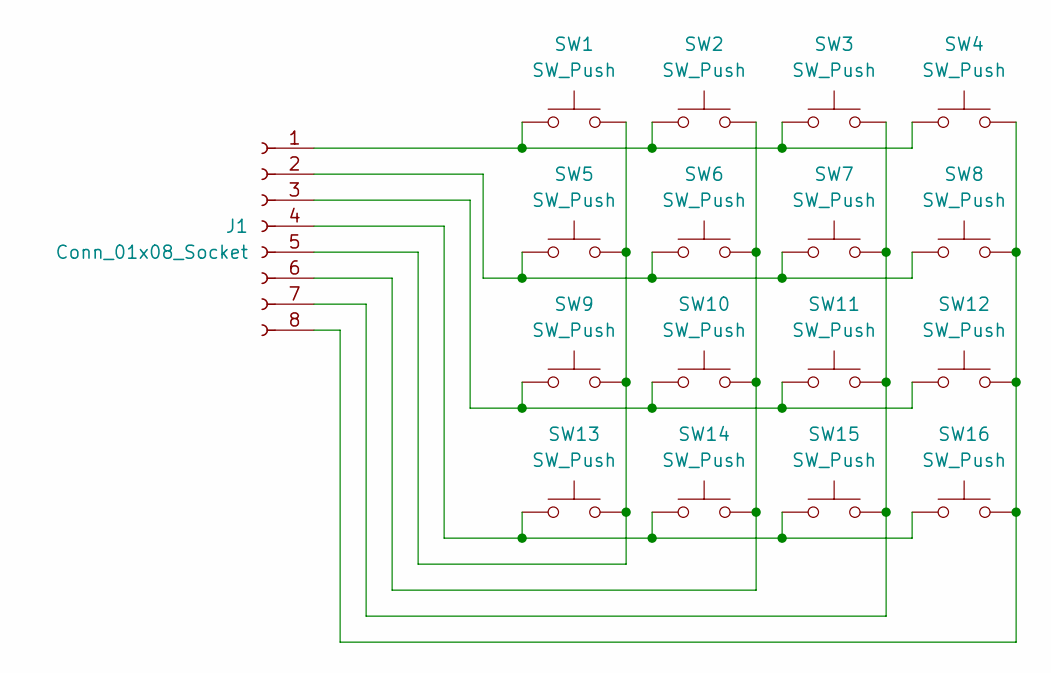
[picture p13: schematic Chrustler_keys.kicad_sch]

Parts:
J1: Conn_01x08_Socket; PinSocket_1x08_P2.54mm_Vertical
SW1, SW2, SW3, SW4, SW5, SW6, SW7, SW8, SW9, SW10, SW11, SW12, SW13, SW14, SW15, SW16: SW_Push; SW_Cherry_MX_1.00u_PCB

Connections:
unnamed: J1.1, SW1.1, SW2.1, SW3.1, SW4.1
unnamed: J1.2, SW5.1, SW6.1, SW7.1, SW8.1
unnamed: J1.3, SW9.1, SW10.1, SW11.1, SW12.1
unnamed: J1.4, SW13.1, SW14.1, SW15.1, SW16.1
unnamed: J1.5, SW1.2, SW5.2, SW9.2, SW13.2
unnamed: J1.6, SW2.2, SW6.2, SW10.2, SW14.2
unnamed: J1.7, SW3.2, SW7.2, SW11.2, SW15.2
unnamed: J1.8, SW4.2, SW8.2, SW12.2, SW16.2

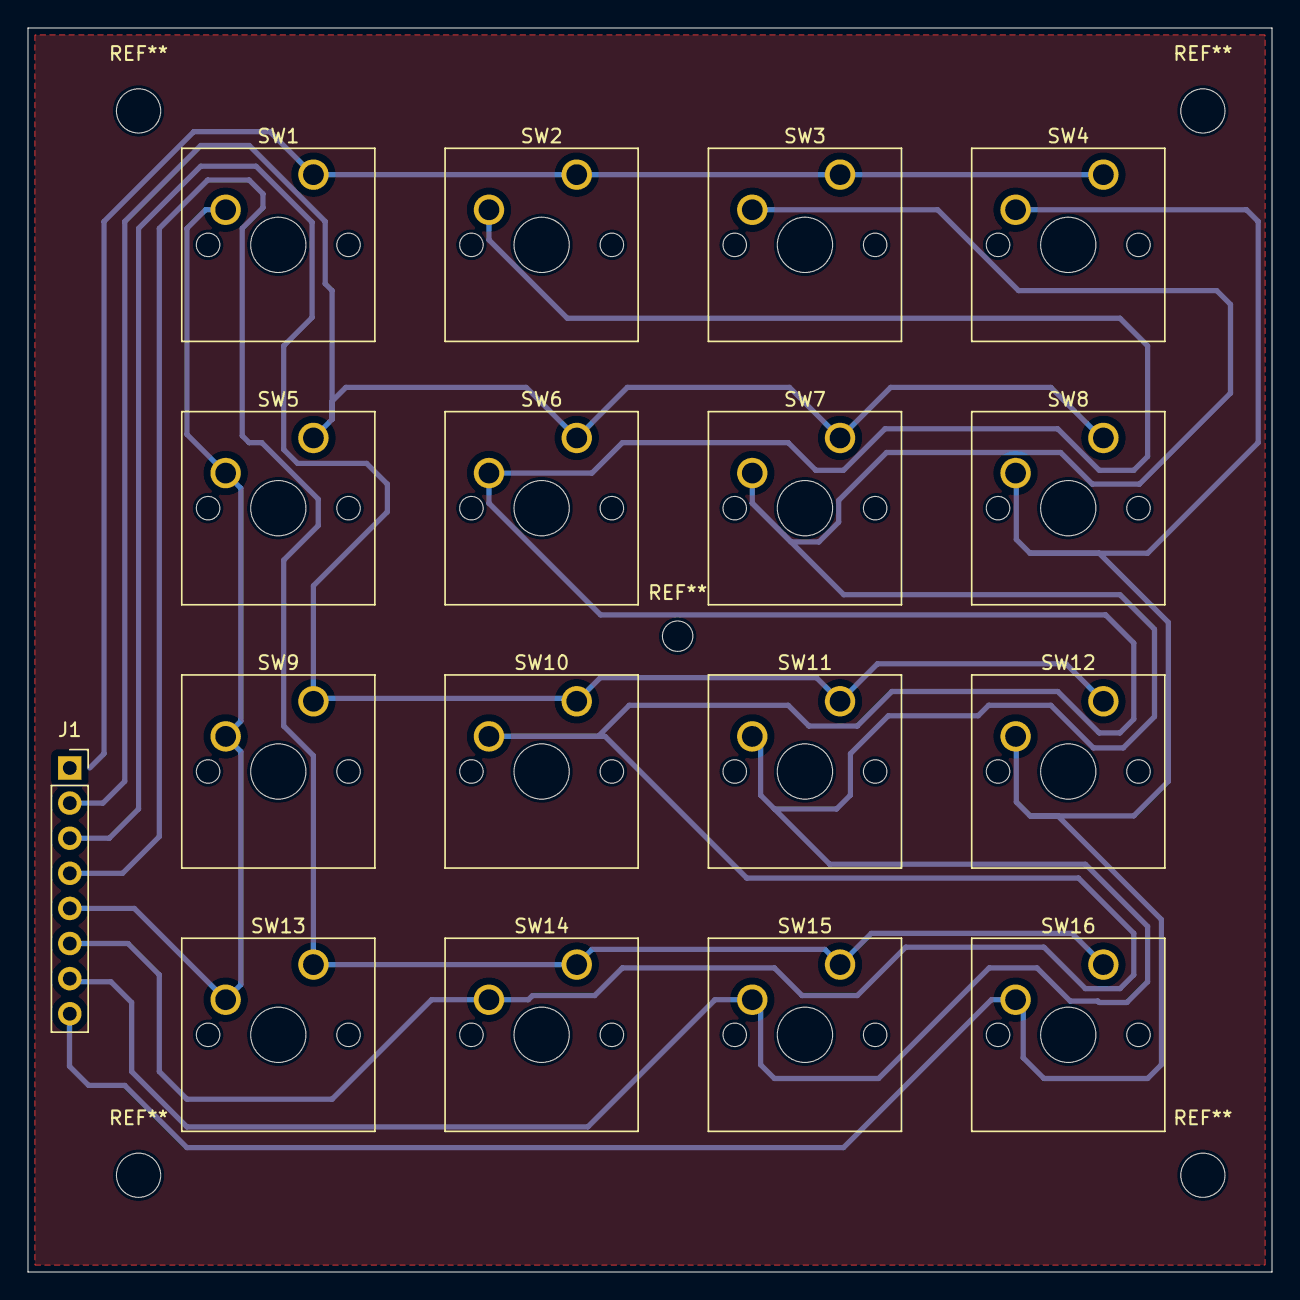
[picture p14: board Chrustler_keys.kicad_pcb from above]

Board: 2 copper layers, 90.0 x 90.0 mm, 17 parts (0 on the bottom side), 8 nets.

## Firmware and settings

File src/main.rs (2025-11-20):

use awedio::{backends::{CpalBackend, CpalBufferSize}, manager::Manager, sounds::{MemorySound, wrappers::{AdjustableSpeed, Controllable, Controller, Pausable, Stoppable}}, *};
use nix::libc::major;
use pitch_detection::{detector::{mcleod::McLeodDetector, PitchDetector}, *};
use rppal::{gpio::{Event, Gpio, InputPin, Trigger}, i2c::I2c};
use core::num;
use std::{env, fmt::format, fs, path, sync::{Arc, Mutex, atomic::{AtomicBool, AtomicI64, AtomicU16}}, thread::{current, sleep}, time::{Duration, Instant}};
use std::fs::File;
use std::io::Read;
use embedded_graphics::{
    mono_font::{MonoTextStyleBuilder, ascii::{FONT_6X10, FONT_8X13}},
    pixelcolor::BinaryColor,
    prelude::*,
    text::{Baseline, Text},
};
use ssd1306::{mode::BufferedGraphicsMode, prelude::*, I2CDisplayInterface, Ssd1306};
use vl53l1x::{Vl53l1x, Vl53l1xRangeStatus, CalibrationData, CustomerNvmManaged, AdditionalOffsetCalData, OpticalCentre, GainCalibrationData, CalPeakRateMap};
use mcp23017::MCP23017;
use num_traits::pow::Pow;

// use crate::keypad::*;
// use crate::encoders::*;
// use crate::tof::*;
mod keypad;
mod encoders;
mod tof;
use tof::CalibrationDataRem;



const SAMPLE_RATE: usize = 48000;
const SIZE: usize = 1024;
const PADDING: usize = SIZE / 2;
const POWER_THRESHOLD: f64 = 0.0001;
const CLARITY_THRESHOLD: f64 = 0.25;

const TEMP_PIN: u8 = 27;
const TOF_INT_PIN: u8 = 17;

const DEFAULT_EQ_LEVEL: u16 = 12;
const VOL_LUT: [u16; 76] = [0,5,9,13,17,20,24,26,29,32,34,37,39,41,43,45,47,48,50,52,53,55,56,58,59,60,61,63,64,65,66,67,68,70,71,72,73,74,75,75,76,77,78,79,80,81,81,82,83,84,85,85,86,87,87,88,89,89,90,91,91,92,93,93,94,94,95,96,96,97,97,98,98,99,99,100];

const TRIADS: u16 = 3;
const SEVENTHS: u16 = 4;
const NINTHS: u16 = 5;

const MAJ_MUL: [f64; 15] = [1.0, 1.1225, 1.2599, 1.3348, 1.4983, 1.6818, 1.887, 2.0, 2.2449, 2.5198, 2.6697, 2.9966, 3.3636, 3.7755, 4.0];
const MIN_MUL: [f64; 15] = [1.0, 1.1225, 1.1892, 1.3348, 1.4983, 1.5874, 1.7818, 2.0, 2.2449, 2.3784, 2.6697, 2.9966, 3.1748, 3.5636, 4.0];

const INPUT_TIMEOUT: u64 = 150;
const FULLSCREEN_TIMEOUT: u64 = 75;

#[derive(Clone, Copy)]
enum Chords {
    I,
    i,
    ii,
    iid,
    III,
    iii,
    IV,
    iv,
    V,
    v,
    vi,
    VI,
    vii,
    VII
}

impl Chords {
    fn note_indices(self) -> Vec<u16> {
        match self {
            Chords::I => vec![1, 3, 5, 7, 9],
            Chords::i => vec![1, 3, 5, 7, 9],
            Chords::ii => vec![2, 4, 6, 8, 10],
            Chords::iid => vec![2, 4, 6, 8, 10],
            Chords::III => vec![3, 5, 7, 9, 11],
            Chords::iii => vec![3, 5, 7, 9, 11],
            Chords::IV => vec![4, 6, 8, 10, 12],
            Chords::iv => vec![4, 6, 8, 10, 12],
            Chords::V => vec![5, 7, 9, 11, 13],
            Chords::v => vec![5, 7, 9, 11, 13],
            Chords::vi => vec![6, 8, 10, 12, 14],
            Chords::VI => vec![6, 8, 10, 12, 14],
            Chords::vii => vec![7, 9, 11, 13, 15],
            Chords::VII => vec![7, 9, 11, 13, 15]
        }
    }
}

#[derive(Clone, Copy, Debug)]
enum Key {
    C,
    Cs,
    D,
    Ds,
    E,
    F,
    Fs,
    G,
    Gs,
    A,
    As,
    B
}

const KEYS: [Key; 12] = [Key::C, Key::Cs, Key::D, Key::Ds, Key::E, Key::F, Key::Fs, Key::G, Key::Gs, Key::A, Key::As, Key::B];

impl Key {
    fn frequency(self) -> f64 {
        match self {
            Key::C => {
                261.63
            }
            Key::Cs => {
                277.2
            }
            Key::D => {
                283.66
            }
            Key::Ds => {
                311.1
            }
            Key::E => {
                329.63
            }
            Key::F => {
                349.23
            }
            Key::Fs => {
                370.0
            }
            Key::G => {
                382.0
            }
            Key::Gs => {
                415.3
            }
            Key::A => {
                440.0
            }
            Key::As => {
                466.2
            }
            Key::B => {
                493.88
            }
        }
    }
}

#[derive(Clone, Copy)]
enum Octave {
    LOW,
    MID,
    HIGH
}
type SoundTup = (Controllable<Stoppable<AdjustableSpeed<MemorySound>>>, Controller<Stoppable<AdjustableSpeed<MemorySound>>>);
fn main() {
    // Setup
    let mut volume: i64 = 75;
    let vol_string = format!("{}%", VOL_LUT[volume as usize]);
    let vol = vol_string.as_str();
    let _amix = std::process::Command::new("amixer")
        .args(vec!["-c", "1", "cset", "numid=6", vol])
        .spawn().expect("Failed to launch amixer!");
    
    let mut int_io = true;

    let gpio = Gpio::new().expect("failed to init gpio");
    let i2c = rppal::i2c::I2c::new().expect("failed to open I2C bus!");
    let mut ex_gpio = MCP23017::new(i2c, 0x27).expect("failed to initialize GPIO expander");
    ex_gpio.init_hardware();


    // using an alternate address: https://docs.rs/ssd1306/latest/ssd1306/struct.I2CDisplayInterface.html

    let i2c = rppal::i2c::I2c::new().expect("failed to open I2C bus!");
    let interface = I2CDisplayInterface::new_custom_address(i2c, 0x3C);
    let mut display = Ssd1306::new(
        interface,
        DisplaySize128x64,
        DisplayRotation::Rotate0,
    ).into_buffered_graphics_mode();
    display.init().unwrap();

    set_io(false, &mut display);
        // init display, set message

        // init filters
    tof::init_eq();
    
        // init TOF sensor & interrupt
    
    let tof_enabled_low: Arc<AtomicBool> = Arc::new(AtomicBool::new(true));
    let tof_enabled_high: Arc<AtomicBool> = Arc::new(AtomicBool::new(true));
    let pass_enabled_low = tof_enabled_low.clone(); 
    let pass_enabled_high= tof_enabled_high.clone(); 
    let tof_sensor: Arc<Mutex<Vl53l1x>> = Arc::new(Mutex::new(tof::init_tof()));
    let thr_sens = tof_sensor.clone();
    let main_thr_sens = tof_sensor.clone();
    
    let mut calibration_lock = main_thr_sens.lock().expect("failed to get TOF lock for calibration");
    let _ = match File::open("calibration.ron") {
        Ok(mut calibration_file) => {
            let mut calibration_string= String::new();
            match calibration_file.read_to_string(&mut calibration_string) {
                Ok(_) => {}
                Err(_) => {
                    drop(calibration_lock);
                    fullscreen_msg(&mut display, "TOF Calibration".to_string());
                    tof::calibration(main_thr_sens.clone());
                    return
                }
            }

            let mut de = ron::Deserializer::from_str(&calibration_string).expect("failed to deserialize!");
            match CalibrationDataRem::deserialize(&mut de) {
                Ok(mut calibration_data) => {
                    // let data_wrap:  CalibrationDataRem = calibration_data;
                    // let mut calibration_data: CalibrationData = data_wrap.into();
                    calibration_lock.set_calibration_data(&mut calibration_data);
                    drop(calibration_lock);
                } 
                Err(_) => {
                    drop(calibration_lock);
                    fullscreen_msg(&mut display, "TOF Calibration".to_string());
                    tof::calibration(main_thr_sens.clone());
                }
            }
        }

        Err(_) => {
            drop(calibration_lock);
            fullscreen_msg(&mut display, "TOF Calibration".to_string());
            tof::calibration(main_thr_sens.clone());
        }
    };
    
    let cur_roi: tof::ROIRight = tof::ROIRight::new(true);
    let cur_lpf: Arc<AtomicU16> = Arc::new(AtomicU16::new(DEFAULT_EQ_LEVEL));
    let cur_hpf: Arc<AtomicU16> = Arc::new(AtomicU16::new(DEFAULT_EQ_LEVEL));
    let pass_lpf = cur_lpf.clone();
    let pass_hpf = cur_hpf.clone();
    let mut tof_int_pin = gpio.get(TOF_INT_PIN).expect("failed to get tof interrupt pin").into_input();
    tof_int_pin.set_async_interrupt(Trigger::FallingEdge, None, move |e| tof::tof_eq_int(e, thr_sens.clone(), &cur_roi, pass_hpf.clone(), pass_lpf.clone(), &pass_enabled_low, &pass_enabled_high)).expect("failed to setup TOF interrupt");
    let mut sensor = main_thr_sens.lock().expect("failed to lock sensor to begin ranging");
    sensor.start_ranging(vl53l1x::DistanceMode::Short).expect("failed to begin tof ranging");
    drop(sensor);

        // init encoders & interrupt
    let mut enc_a_DT = gpio.get(encoders::ENC_A_DT).expect("couldn't get GPIO").into_input();
    let mut enc_a_CLK= gpio.get(encoders::ENC_A_CLK).expect("couldn't get GPIO").into_input();
   
    let mut enc_b_DT = gpio.get(encoders::ENC_B_DT).expect("couldn't get GPIO").into_input();
    let mut enc_b_CLK= gpio.get(encoders::ENC_B_CLK).expect("couldn't get GPIO").into_input();
    let mut last_counter_a: i64 = 0;
    let mut last_counter_b: i64 = 0;
    let counter_a = Arc::new(AtomicI64::new(0));
    let counter_b = Arc::new(AtomicI64::new(0));
    let counter_a_int = counter_a.clone();
    let counter_b_int = counter_b.clone();
    let _ =  enc_a_CLK.set_async_interrupt(rppal::gpio::Trigger::FallingEdge, Some(Duration::from_millis(7)),  move |e| encoders::encoder_pos(e, &enc_a_DT, &counter_a_int));
    let _ = enc_b_CLK.set_async_interrupt(rppal::gpio::Trigger::FallingEdge, Some(Duration::from_millis(7)),  move |e| encoders::encoder_pos(e, &enc_b_DT, &counter_b_int));
 
    let enc_a_pb = gpio.get(encoders::ENC_A_PB).expect("couldn't get GPIO").into_input_pullup();
    let enc_b_pb = gpio.get(encoders::ENC_B_PB).expect("couldn't get GPIO").into_input_pullup();


        // init keypad
    let i2c = rppal::i2c::I2c::new().expect("failed to open I2C bus!");
    keypad::init_keypad(i2c);
        // TODO: Search for sample file names
        // automatically select sound_xx where xx is the largest integer found there, and record xx + 1 as the next sample name

    // Setup audio backend
    let mut backend =
        backends::CpalBackend::with_default_host_and_device(1,48000,CpalBufferSize::Default).ok_or(backends::CpalBackendError::NoDevice).expect("failed to initilize cpal backend!");
    let mut manager = backend.start(|error| eprintln!("error with cpal output stream: {}", error)).expect("failed to initialize sound manager!");

    let mut next_sample_no: usize = 0;
    let mut sample_paths: Vec<String> = Vec::new();

    // These three file operations should not fail on a Pi with user logged in.
    let mut media_users= fs::read_dir("/media").expect("No '/media' Directory!"); // list users
    let user_media = media_users.next().unwrap().expect("No media users!"); // get user dir
    let mut user_media_dir = fs::read_dir(user_media.path()).expect("No USB media!"); // list user drives
    // ^^^

    // If the usb drive is plugged in use that, if not default to CWD
    let mut media_path_entry = match user_media_dir.next() {
        Some(usb_media_path) => {
            usb_media_path.expect("No USB media!").path() // get user drive
        }
        None => {
            env::current_dir().expect("No current working dir!")
        }
    };
    
    println!("using {:#?}", media_path_entry);
    let user_media_dir = match fs::read_dir(media_path_entry.clone()) { // list user drive files
         Ok(dir) => dir,
         Err(_) => {
            println!("using {:#?}", media_path_entry);
            media_path_entry = env::current_dir().expect("No current working dir!");
            fs::read_dir(media_path_entry.clone()).expect("failed to read CWD!")
         }
    };
    let media_path = media_path_entry.to_str().unwrap().to_string();
    
    for entry_res in user_media_dir {
        match entry_res {
            Ok(entry) => {
                if entry.path().extension().is_some() {
                    if entry.path().extension().unwrap().to_str().is_some() {
                        if entry.path().extension().unwrap().to_str().unwrap().eq("wav") {
                            let this_path = entry.path().to_str().unwrap().to_string();
                            sample_paths.push(entry.path().to_str().unwrap().to_string());
                            let after_slash = this_path.rfind("/").unwrap() + 1;
                            let dot = this_path.find(".").unwrap();
                            if this_path[after_slash..after_slash + 6].eq("sound_") {
                                println!("found '{}'", this_path);
                                match this_path[after_slash + 6..dot].parse() {
                                    Ok(sampleno) => {
                                        if sampleno > next_sample_no {
                                            next_sample_no = sampleno;
                                        }
                                    }
                                    Err(_) => {}
                                }
                            }
                        }
                    }
                }
            }
            Err(_) => {}
        }
    }

    next_sample_no = next_sample_no + 1;

    let mut current_sample_idx: usize = 0;
    let init_smpl_path = if sample_paths.len() > 0 {
        sample_paths[current_sample_idx].clone()
    } else {
        "test_arec.wav".to_string()
    };

    let wav_sound = awedio::sounds::open_file(init_smpl_path).expect("couldn't open audio file");
    let mut test_sound = wav_sound.into_memory_sound().expect("Could not make memory sound");
    let mut sound = test_sound.clone();

    let mut samples: [f64; 1024] = [0.0; 1024];
    for i in 0..1024 {
        samples[i] = match test_sound.next_sample().expect("not enough samples!") {
            NextSample::Sample(s) =>  {
                let test_sample = (s as f64) / 32768.0;
                test_sample
            },
            _ => 0.0
        };
    }
    
    let mut detector = McLeodDetector::new(SIZE, PADDING);

        // detect frequency and TODO: record frequency
    let pitch = detector
        .get_pitch(&samples, SAMPLE_RATE, POWER_THRESHOLD, CLARITY_THRESHOLD)
        .unwrap();
    let mut current_freq: f64 = pitch.frequency;

    let mut key =  Key::C;
    let mut key_idx = 0;
    //let correction: f64 = key.frequency() / (current_freq as f64);
    let mut major = true;
    let mut chord_type = TRIADS;
        // init scale and mode to C major
        // init chords to triads
    let mut current_octave = Octave::MID;
        // init 14 sound "cache" array
    let mut sound_cache: 
        Vec<SoundTup> 
        = Vec::new();
        // init current notes vector
    change_octave_key(sound.clone(), current_freq, &mut sound_cache, key, current_octave, major);

    let mut current_notes: 
        Vec<Controller<Stoppable<AdjustableSpeed<MemorySound>>>> 
        = Vec::new();

    let mut hold = false;
    let mut gate = false;
    let mut last_input: Option<keypad::Keypad> = None;
    loop {
        
        // match keypad input
        match keypad::get_keypad(&mut ex_gpio, last_input) {
            // ZERO - Play root note
            Some(keypad::Keypad::ZERO) => {
                if last_input != Some(keypad::Keypad::ZERO) {
                    hold = false;
                    gate_sound(chord_type, &mut current_notes);
                    let correction = match current_octave{
                        Octave::LOW => {
                            (key.frequency()/2.0) / (current_freq as f64)
                        }
                        Octave::MID => {
                            (key.frequency()) / (current_freq as f64)
                        }
                        Octave::HIGH => {
                            (key.frequency() * 2.0) / (current_freq as f64)
                        }
                    };
                        let (play_snd, ctrl_snd) = sound_cache.remove((0) as usize);
                        manager.play(Box::new(play_snd));
                        current_notes.push(ctrl_snd);
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

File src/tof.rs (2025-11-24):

use serde::{Deserialize, Serialize};
use vl53l1x::{Vl53l1x, Vl53l1xRangeStatus, CalibrationData, CustomerNvmManaged, AdditionalOffsetCalData, OpticalCentre, GainCalibrationData, CalPeakRateMap};
use rppal::{gpio::{Event, Gpio, Trigger}, i2c::I2c};
use std::{env, fs::{self, File}, io, sync::{Arc, Mutex, atomic::{AtomicBool, AtomicU16}}, thread::sleep, time::Duration};

pub enum FilterType {
    HPF,
    LPF,
}
pub type ROIRight = AtomicBool;

pub fn init_eq() {
    let _amix_en = std::process::Command::new("amixer")
        .args(vec!["-c", "1", "cset", "numid=9", "on"])
        .spawn().expect("Failed to launch amixer!");
    sleep(std::time::Duration::from_millis(50));
    for freq in 10..15 {
        let numid_string = format!("numid={}", freq);
        let numid= numid_string.as_str();
        let _amix = std::process::Command::new("amixer")
            .args(vec!["-c", "1", "cset", numid, "12"])
            .spawn().expect("Failed to launch amixer!");
    }
}

fn set_eq(freq: u8, level: i8) {
    if freq > 5 || freq == 0 || level < 0 {
        return;
    }
    let numid_string = format!("numid={}", (freq + 9));
    let numid= numid_string.as_str();
    let lev_string = level.to_string();
    let lev = lev_string.as_str();
    let _amix = std::process::Command::new("amixer")
        .args(vec!["-q", "-c", "1", "cset", numid, lev])
        .output();
    // pray this doesn't cause any issues...

}

pub fn init_tof() -> Vl53l1x {
    let mut tof_sensor = Vl53l1x::new(1, None).expect("Failed to create TOF sensor struct");
    tof_sensor.soft_reset().expect("Failed to reset TOF sensor");
    tof_sensor.init().expect("Failed to init TOF sensor");
    tof_sensor.set_measurement_timing_budget(20000).expect("failed to set measurement timing");
    tof_sensor.set_inter_measurement_period(24).expect("failed to set inter-measurement timing");

    tof_sensor.set_user_roi(8, 15, 15, 0).expect("failed to set ROI Right");
    
    println!("initilized TOF sensor");
    return tof_sensor;
}

pub fn tof_eq_int(_event: Event, tof_sensor: Arc<Mutex<Vl53l1x>>, cur_roi: &ROIRight, cur_hpf: Arc<AtomicU16>, cur_lpf: Arc<AtomicU16>, enabled_low: &Arc<AtomicBool>, enabled_high: &Arc<AtomicBool>) {
    //println!("TOF interrupt");
    let mut sensor = tof_sensor.lock().expect("failed to acquire sensor lock");
    let sample = sensor.read_sample().expect("failed to get right sample");
    //println!("sampled: {}mm ({:#?})", sample.distance, sample.status);
    let low_enabled = enabled_low.load(std::sync::atomic::Ordering::SeqCst);
    let high_enabled = enabled_high.load(std::sync::atomic::Ordering::SeqCst);
    if low_enabled ||  high_enabled{
        match sample.status {
            Vl53l1xRangeStatus::Ok => {
                let filter_strength: i8 = if sample.distance < 240 {
                    (sample.distance/20).try_into().unwrap()
                } else {
                    12
                };
                if cur_roi.load(std::sync::atomic::Ordering::SeqCst) {
                    set_filter(FilterType::LPF, filter_strength, cur_hpf, cur_lpf);
                    if low_enabled {    
                        cur_roi.store(false, std::sync::atomic::Ordering::SeqCst);
                        sensor.set_user_roi(0, 10, 3, 6).expect("failed to set ROI Left during interrupt");
                    }
                } else {
                    set_filter(FilterType::HPF, filter_strength, cur_hpf, cur_lpf);
                    if high_enabled {
                        cur_roi.store(true, std::sync::atomic::Ordering::SeqCst);
                        sensor.set_user_roi(12, 10, 15, 6).expect("failed to set ROI Right during interrupt");
                    }
                }
            }
            _ => {}
        }
    }
}

fn set_filter(filter: FilterType, strength: i8, cur_hpf: Arc<AtomicU16>, cur_lpf: Arc<AtomicU16>) {
    match filter {
        FilterType::LPF => {
            set_eq(1, strength);

            if strength < 12 {
                set_eq(2, strength/2);
            } else {
                set_eq(2, strength);
            }
            cur_lpf.store(strength as u16, std::sync::atomic::Ordering::SeqCst);
        },
        FilterType::HPF => {
            set_eq(5, strength);

            if strength < 12 {
                set_eq(4, strength/2);
            } else {
                set_eq(4, strength);
            }
            cur_hpf.store(strength as u16, std::sync::atomic::Ordering::SeqCst);
        }
    }
}

pub fn calibration(tof_mut: Arc<Mutex<Vl53l1x>>) {
    let mut tof = tof_mut.lock().expect("failed to get TOF lock for calibration");
    
    println!("Ensure TOF sensor is clear and press ENTER to preform SPAD calibration");
    io::stdin().read_line(&mut "".to_string()).expect("Failed to read line"); 
    tof.perform_ref_spad_management().expect("failed SPAD calibration!");
    
    tof.set_measurement_timing_budget(30000);
    tof.set_inter_measurement_period(40);
    println!("Ensure calibration card is 140mm from sensor and press ENTER to preform offset calibration");
    io::stdin().read_line(&mut "".to_string()).expect("Failed to read line"); 
    tof.perform_offset_simple_calibration(140).expect("failed offset calibration!");
    println!("finished offset calibration");
    
    tof.set_measurement_timing_budget(30000);
    tof.set_inter_measurement_period(40);
    println!("Ensure calibration card is 600mm from sensor and press ENTER to preform cross-talk calibration");
    io::stdin().read_line(&mut "".to_string()).expect("Failed to read line"); 
    tof.perform_single_target_xtalk_calibration(600).expect("failed cross-talk calibration!");
   println!("finished xtalk calibration");

    let mut cal_data: CalibrationData = CalibrationData::new();
    //io::stdin().read_line(&mut "".to_string()).expect("Failed to read line"); 
    tof.get_calibration_data(&mut cal_data).expect("failed to get calibration data from sensor");
    println!("writing calibration data to disk");
    let data_file = File::create("calibration.ron").expect("couldn't create calibration data file!");
    let mut se = ron::Serializer::new(data_file, None).expect("failed to serialize calibration data");
    CalibrationDataRem::serialize(&cal_data, &mut se);
}


#[derive(Debug, serde::Serialize, serde::Deserialize)]
#[serde(remote = "CalibrationData")]
#[repr(C)]
pub struct CalibrationDataRem {
	struct_version: u32,
    #[serde(with = "CustomerNvmManagedRem")]
	customer: CustomerNvmManaged,
    #[serde(with = "AdditionalOffsetCalDataRem")]
    add_off_cal_data: AdditionalOffsetCalData,
    #[serde(with = "OpticalCentreRem")]
	optical_centre: OpticalCentre,
    #[serde(with = "GainCalibrationDataRem")]
	gain_cal: GainCalibrationData,
    #[serde(with = "CalPeakRateMapRem")]
	cal_peak_rate_map: CalPeakRateMap,
}
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

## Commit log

2025-11-11 fix filter strength
2025-11-11 fix hi octave display
    [main.rs]
2025-11-12 tof debug print
2025-11-12 add filter level display
2025-11-12 remove tof print
2025-11-12 fix maj/minor cache flush
    [main.rs]
2025-11-12 fix? key change and volume display
    [keypad.rs, main.rs]
2025-11-13 fix up a couple things
    [main.rs]
2025-11-13 hopefully one last mistake for file selection fixed
    [main.rs]
2025-11-13 sample select rollover fix?
    [main.rs]
2025-11-13 forgot about gating for sample select
2025-11-13 fix filename parsing + delay after error screen
    [main.rs]
2025-11-14 try fixing buffer size
    [main.rs]
2025-11-17 add internal/external io switching
2025-11-17 fix ghost USB possibility and update TOF ROIs
    [main.rs, tof.rs]
2025-11-17 fix root note playback
    [main.rs]
2025-11-18 add calibration functionality
2025-11-19 i'm too tired to be coding rn
2025-11-20 add a couple of missed tof updates
    [main.rs]
2025-11-20 start README/writeup
    [crustler chassis.scad, soundcard standoff.scad]
2025-11-20 I messed up the filter function again
2025-11-20 add more scad files, and keypad PCB
    [Chrustler_keys.kicad_pcb, Chrustler_keys.kicad_sch, Riskable Profile 4.0 (Homing Dot).stl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]
